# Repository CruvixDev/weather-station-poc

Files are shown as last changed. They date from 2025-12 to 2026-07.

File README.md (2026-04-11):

# Weather station POC (Proof Of Concept)




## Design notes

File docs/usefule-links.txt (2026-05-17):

https://developer.arm.com/documentation/dui0499/e/arm-dstream-target-interface-connections/swd-connections
https://www.emisoftware.com/calculator/microstrip-capacitance/
https://resources.altium.com/fr/p/pcb-design-and-review-checklist

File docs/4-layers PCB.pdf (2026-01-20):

Thickness: 1.6MM | Finished Outer Copper: 1OZ | Inner Copper: 1OZ | Inner layer Residual copper ratio: 30%
Layer | Material | Thickness
| | | (mm) Thickness after lamination(mm)
| | L1-CU | Outer Base Copper
0.5OZ | 0.0175 | 0.0175
| | | (Plating to 1OZ)
| | PP | 7628 RC46%
DK:4.74 | 0.1960 | 0.1715
L2-CU | Inner Copper 1OZ | 0.0350
| | | 1.1
(Core with Cu) CORE | Core
DK:4.6 | 1.0300
L3-CU | Inner Copper 1OZ | 0.0350
PP | 7628 RC46%
DK:4.74 | 0.1960 | 0.1715
L4-CU | Outer Base Copper
0.5OZ | 0.0175 | 0.0175
(Plating to 1OZ)

L2-CU

L1-CU

PP

## CORE

L3-CU

PP

L4-CU

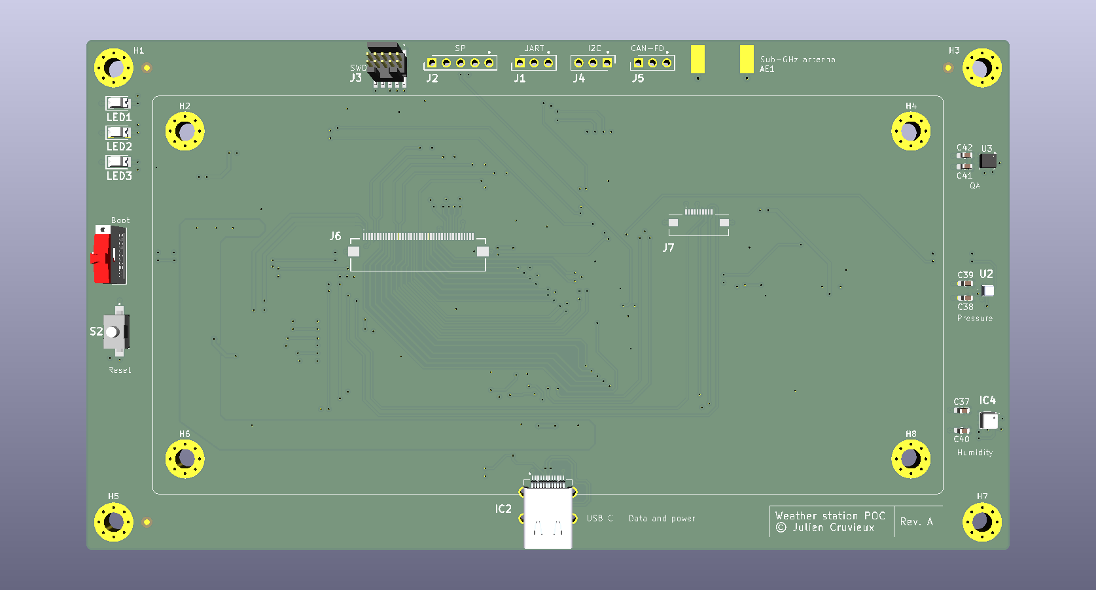
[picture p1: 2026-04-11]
docs/weather-station-poc-top.png

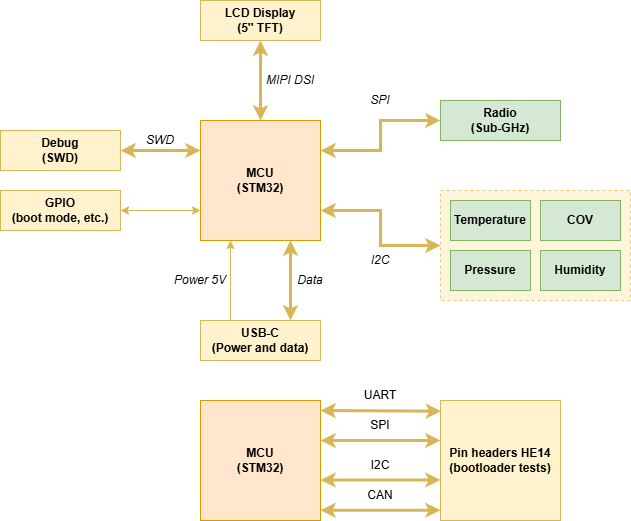
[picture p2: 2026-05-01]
docs/WeatherStationPOC.png

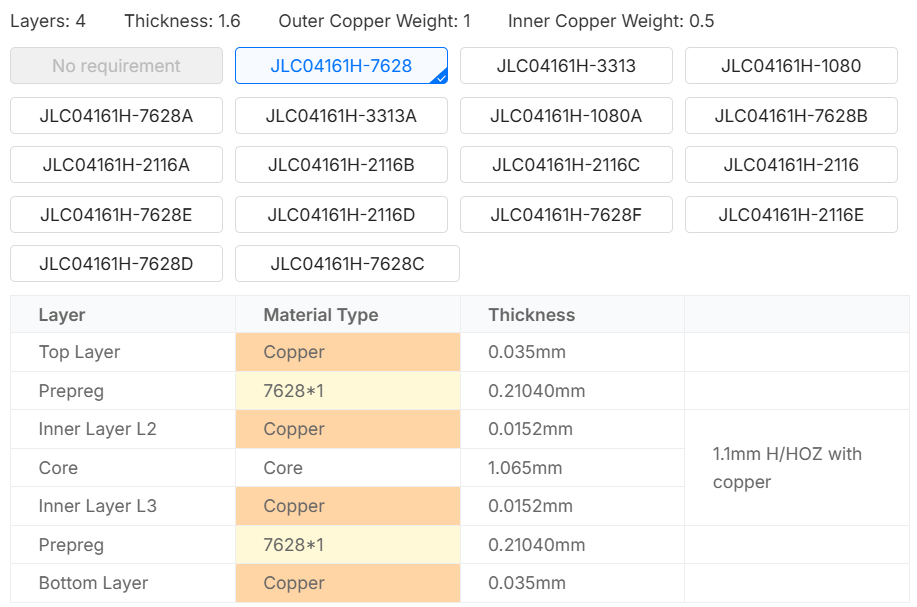
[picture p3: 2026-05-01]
docs/stackup-jlcpcb.png

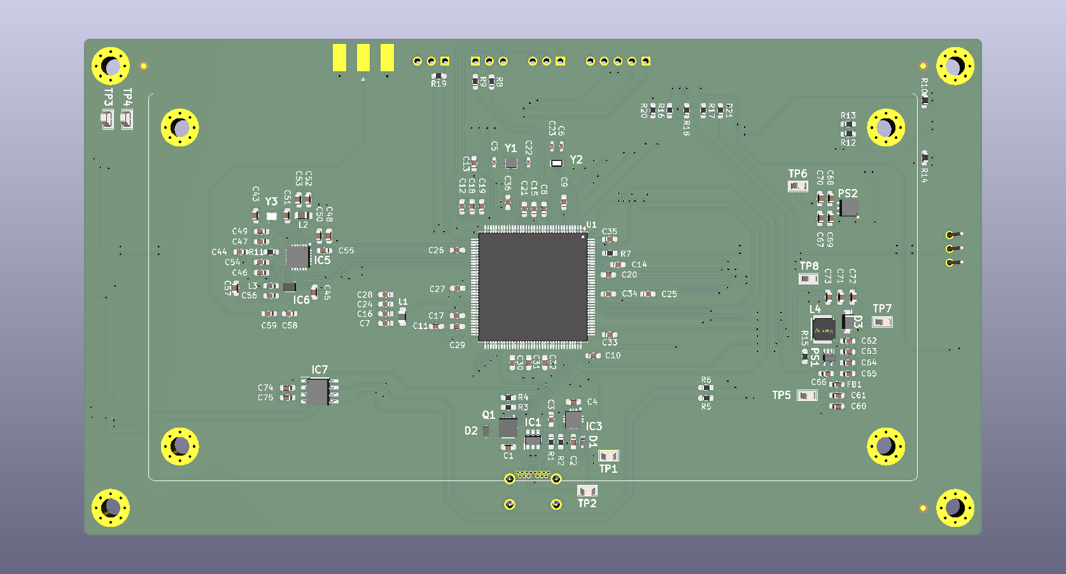
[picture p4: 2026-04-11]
docs/weather-station-poc-bottom.png

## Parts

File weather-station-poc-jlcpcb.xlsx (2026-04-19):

Comment | Designator | Footprint
Antenna | AE1 | Connector_Coaxial:SMA_Molex_73251-1153_EdgeMount_Horizontal
100p | C1,C45,C46,C49,C58 | Capacitor_SMD:C_0603_1608Metric_Pad1.08x0.95mm_HandSolder
100n | C2,C4,C7,C8,C9,C10,C16,C17,C18,C19,C20,C21,C25,C26,C27,C29,C30,C31,C32,C33,C34,C35,C36,C37,C38,C39,C41,C42,C60,C62,C66,C69,C70,C71,C73,C75 | Capacitor_SMD:C_0603_1608Metric_Pad1.08x0.95mm_HandSolder
470p | C3,C54 | Capacitor_SMD:C_0603_1608Metric_Pad1.08x0.95mm_HandSolder
8p | C5,C22 | Capacitor_SMD:C_0402_1005Metric_Pad0.74x0.62mm_HandSolder
3p | C6,C23 | Capacitor_SMD:C_0402_1005Metric_Pad0.74x0.62mm_HandSolder
10u | C11,C15,C61,C63,C64,C65,C74 | Capacitor_SMD:C_0603_1608Metric_Pad1.08x0.95mm_HandSolder
1u | C12,C13,C53,C67,C68 | Capacitor_SMD:C_0603_1608Metric_Pad1.08x0.95mm_HandSolder
4u7 | C14,C48,C72 | Capacitor_SMD:C_0603_1608Metric_Pad1.08x0.95mm_HandSolder
2u2 | C24,C28 | Capacitor_SMD:C_0603_1608Metric_Pad1.08x0.95mm_HandSolder
220n | C40 | Capacitor_SMD:C_0603_1608Metric_Pad1.08x0.95mm_HandSolder
10p | C43 | Capacitor_SMD:C_0603_1608Metric_Pad1.08x0.95mm_HandSolder
150n | C44,C47,C50,C52,C55,C56,C57 | Capacitor_SMD:C_0603_1608Metric_Pad1.08x0.95mm_HandSolder
12p | C51 | Capacitor_SMD:C_0603_1608Metric_Pad1.08x0.95mm_HandSolder
2p7 | C59 | Capacitor_SMD:C_0603_1608Metric_Pad1.08x0.95mm_HandSolder
BAT54KFILM | D1 | weather-station-poc-fp:SODFL1608X70N
ESDA25P35-1U1M | D2 | weather-station-poc-fp:ESDA25P351U1M
SS26FL | D3 | weather-station-poc-fp:SODFL3617X108N
70 | FB1 | Inductor_SMD:L_0603_1608Metric_Pad1.05x0.95mm_HandSolder
USBLC6-2SC6 | IC1 | weather-station-poc-fp:SOT95P280X145-6N
6,32723E+11 | IC2 | weather-station-poc-fp:632723100011
TCPP01-M12 | IC3 | weather-station-poc-fp:QFN50P300X300X100-13N-D
BME690 | IC4 | weather-station-poc-fp:BME690
S2-LPQTR | IC5 | weather-station-poc-fp:QFN50P400X400X100-25N-D
BALF-SPI2-01D3 | IC6 | weather-station-poc-fp:BALFSPI201D3
STSAFA110S8OCD03 | IC7 | weather-station-poc-fp:SOIC127P600X175-8N
61300311121 | J1,J4,J5 | weather-station-poc-fp:HDRV3W64P0X254_1X3_762X254X869P
61300511121 | J2 | weather-station-poc-fp:HDRV5W64P0X254_1X5_1270X254X854P
Conn_ARM_JTAG_SWD_10 | J3 | weather-station-poc-fp:FTSH10501LDVK
6,8714E+11 | J6 | weather-station-poc-fp:687140149022
6,8711E+11 | J7 | weather-station-poc-fp:687110183622
2u2 | L1 | Inductor_SMD:L_0805_2012Metric_Pad1.05x1.20mm_HandSolder
10u | L2 | Inductor_SMD:L_0805_2012Metric_Pad1.05x1.20mm_HandSolder
12n | L3 | Inductor_SMD:L_0603_1608Metric_Pad1.05x0.95mm_HandSolder
10u | L4 | weather-station-poc-fp:INDPM4040X180N
HSMG-C150 | LED1,LED2,LED3 | weather-station-poc-fp:LEDC3216X120N
TPS61169DCKR | PS1 | weather-station-poc-fp:SOT65P210X110-5N
LD39050PU33R | PS2 | weather-station-poc-fp:SON95P300X300X100-7N-D
STL11N3LLH6 | Q1 | weather-station-poc-fp:STL20N6F7
10k | R1,R7,R10,R18,R20,R21 | Resistor_SMD:R_0603_1608Metric_Pad0.98x0.95mm_HandSolder
2k4 | R2 | Resistor_SMD:R_0603_1608Metric_Pad0.98x0.95mm_HandSolder
110k | R3 | Resistor_SMD:R_0603_1608Metric_Pad0.98x0.95mm_HandSolder
200k | R4 | Resistor_SMD:R_0603_1608Metric_Pad0.98x0.95mm_HandSolder
4.7k | R5,R6,R8,R9 | Resistor_SMD:R_0603_1608Metric_Pad0.98x0.95mm_HandSolder
10 | R11 | Resistor_SMD:R_0603_1608Metric_Pad0.98x0.95mm_HandSolder
1k | R12,R14 | Resistor_SMD:R_0603_1608Metric_Pad0.98x0.95mm_HandSolder
2k | R13 | Resistor_SMD:R_0603_1608Metric_Pad0.98x0.95mm_HandSolder
1R5 | R15 | Resistor_SMD:R_0603_1608Metric_Pad0.98x0.95mm_HandSolder
22 | R16,R17 | Resistor_SMD:R_0603_1608Metric_Pad0.98x0.95mm_HandSolder
120 | R19 | Resistor_SMD:R_0603_1608Metric_Pad0.98x0.95mm_HandSolder
4,50301E+11 | S1 | weather-station-poc-fp:450301014042
4,34121E+11 | S2 | weather-station-poc-fp:434121050816
TestPoint | TP1,TP2,TP3,TP4,TP5,TP6,TP7,TP8 | weather-station-poc-fp:5015
STM32U5G9ZJTxQ | U1 | Package_QFP:LQFP-144_20x20mm_P0.5mm
BMP581 | U2 | weather-station-poc-fp:BMP581
BME280 | U3 | Package_LGA:Bosch_LGA-8_2.5x2.5mm_P0.65mm_ClockwisePinNumbering
NX2016SA-16MHZ-EXS00A-CS07826 | Y1 | weather-station-poc-fp:NX2016SA16MHZEXS00ACS07826
NX2012SA-32.768K-STD-MUB-1 | Y2 | weather-station-poc-fp:NX2012SA32768KSTDMUB1
NX1612SA-50M-EXS00A-CS08403 | Y3 | weather-station-poc-fp:NX1612SA50MEXS00ACS08403

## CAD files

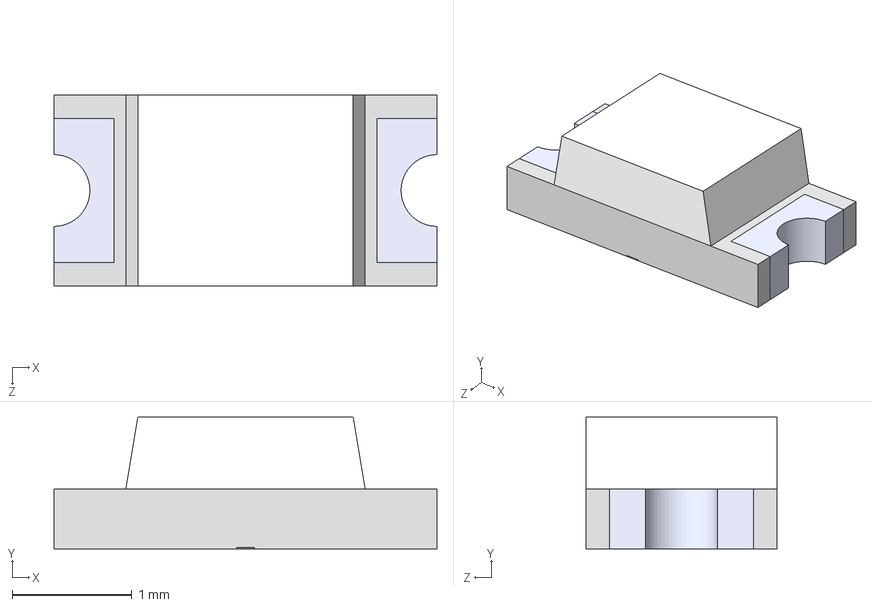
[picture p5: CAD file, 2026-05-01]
3d_models/HSMG-C150.stp
3.20 x 1.10 x 1.60 mm

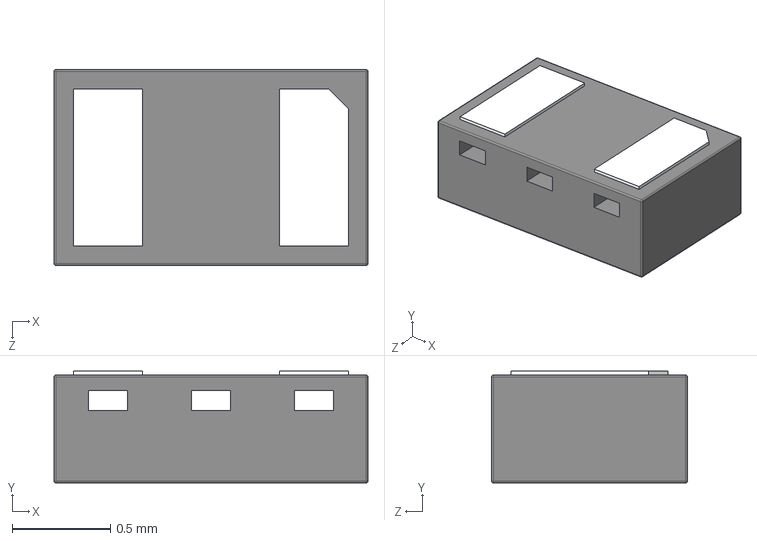
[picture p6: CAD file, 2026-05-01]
3d_models/ESDA25P35-1U1M.stp
1.60 x 0.57 x 1.00 mm

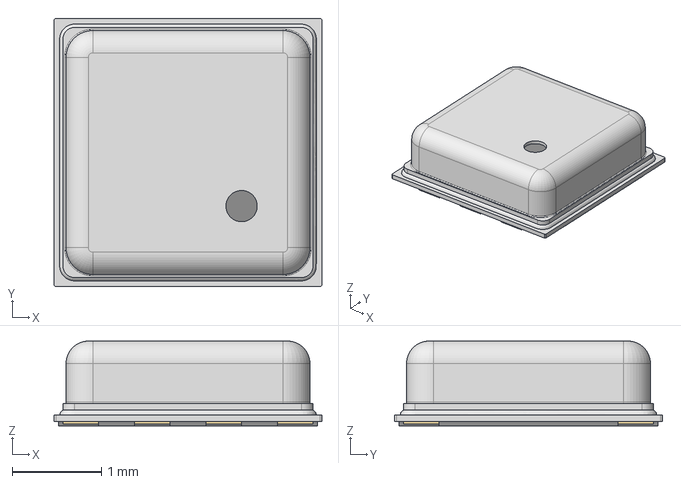
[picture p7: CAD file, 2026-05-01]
3d_models/BME690.stp
3.00 x 3.00 x 0.95 mm

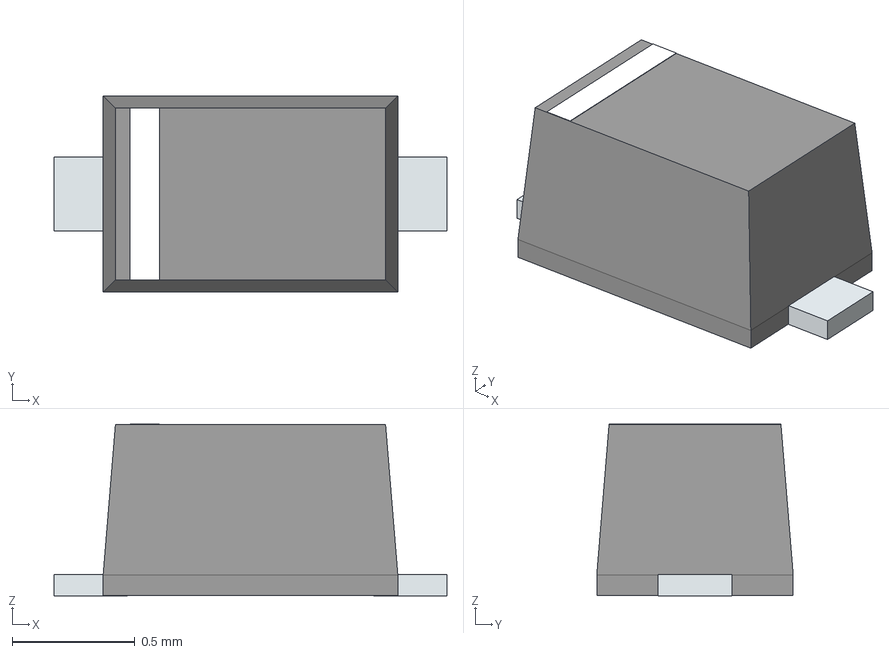
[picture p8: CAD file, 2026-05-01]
3d_models/BAT54KFILM.stp
1.60 x 0.8 x 0.7 mm
PinKIdent
PinK
PinA

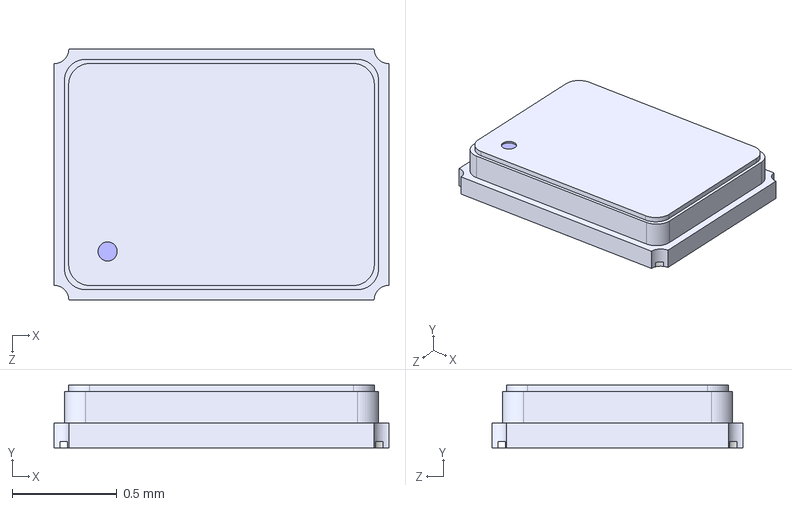
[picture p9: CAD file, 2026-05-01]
3d_models/NX1612SA-50M-EXS00A-CS08403.stp
1.60 x 0.3 x 1.20 mm

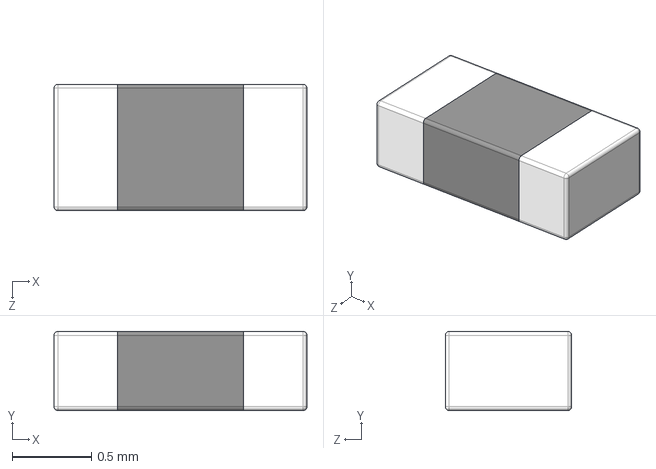
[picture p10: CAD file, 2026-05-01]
3d_models/BLM18SG700TN1D.stp
1.60 x 0.5 x 0.8 mm

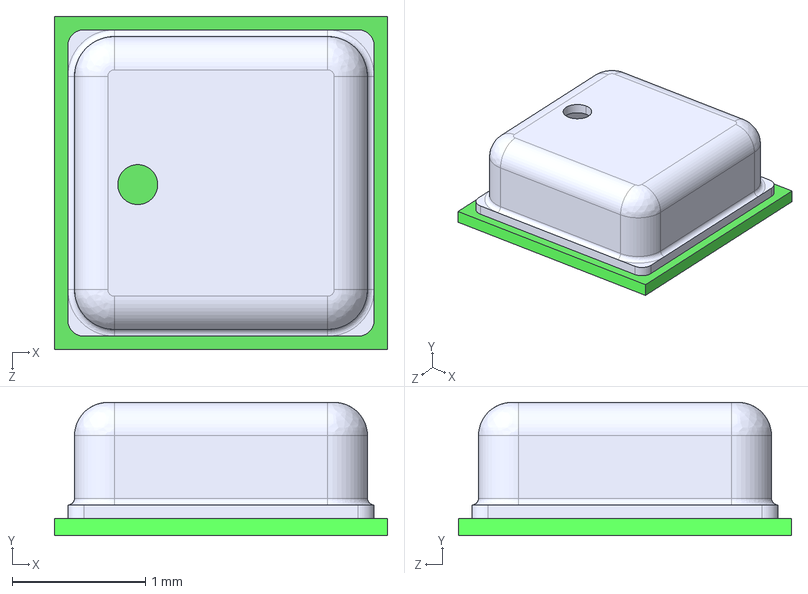
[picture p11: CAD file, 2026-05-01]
3d_models/BME280.stp
2.50 x 1.00 x 2.50 mm

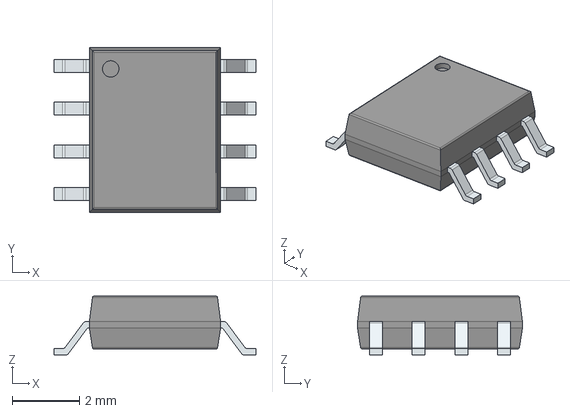
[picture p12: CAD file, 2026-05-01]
3d_models/STSAFA110S8OCD03.stp
6.00 x 4.90 x 1.75 mm
PinsArrayLR

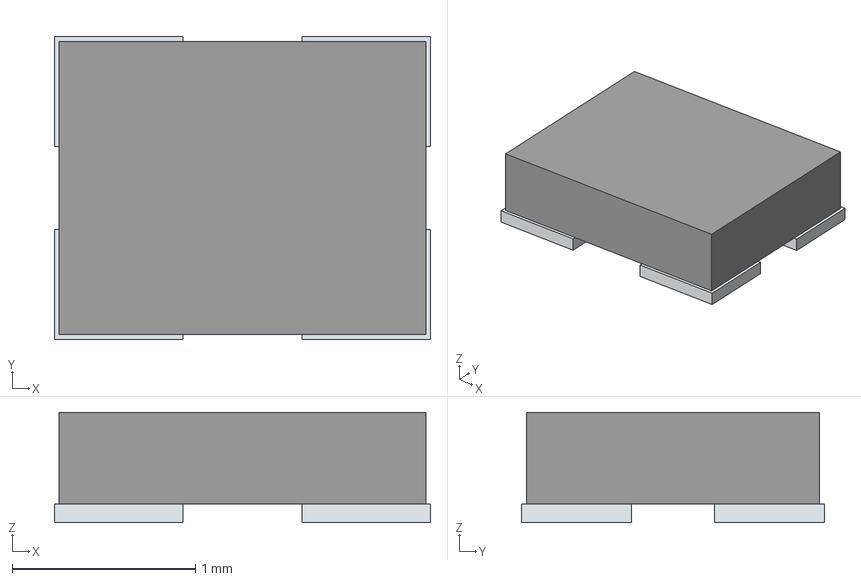
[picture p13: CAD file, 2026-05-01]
3d_models/NX2016SA-16MHZ-EXS00A-CS07826.stp
2.05 x 1.65 x 0.6 mm
Pins

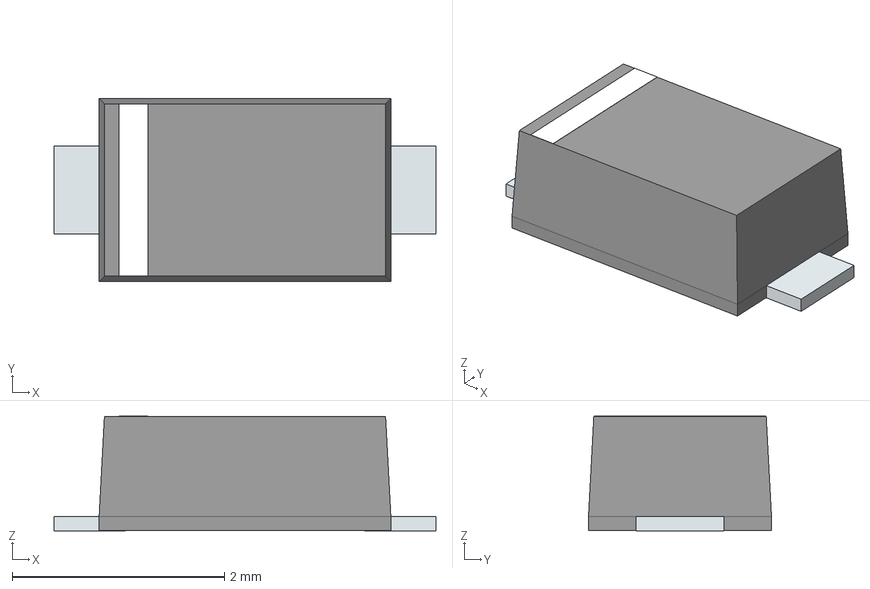
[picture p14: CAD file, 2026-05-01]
3d_models/SS26FL.stp
3.60 x 1.73 x 1.08 mm
PinKIdent
PinK
PinA

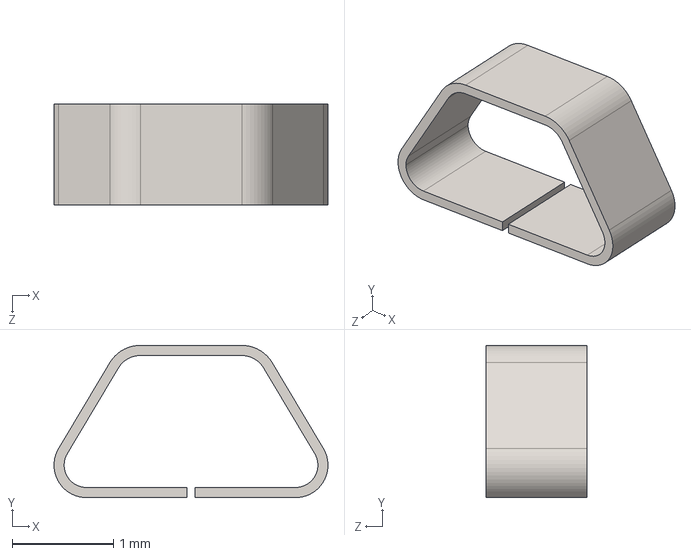
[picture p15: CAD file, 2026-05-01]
3d_models/5015.stp
2.70 x 1.50 x 1.00 mm

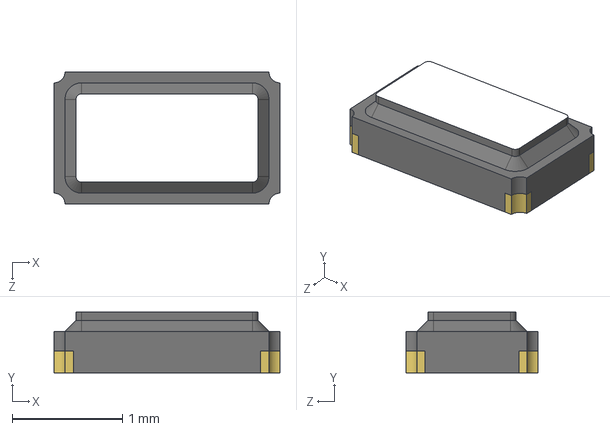
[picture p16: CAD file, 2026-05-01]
3d_models/NX2012SA-32.768K-STD-MUB-1.stp
2.05 x 0.55 x 1.20 mm

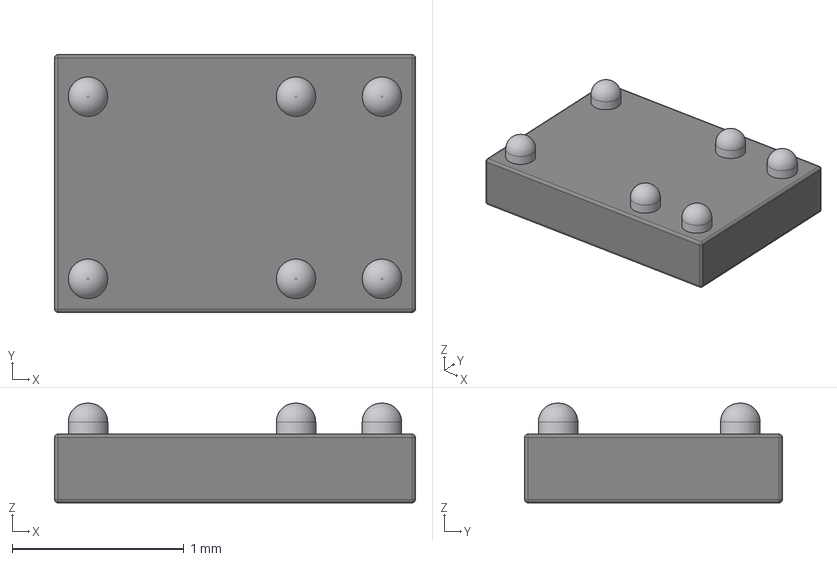
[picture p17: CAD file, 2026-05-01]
3d_models/BALF-SPI2-01D3.stp
2.10 x 1.50 x 0.58 mm

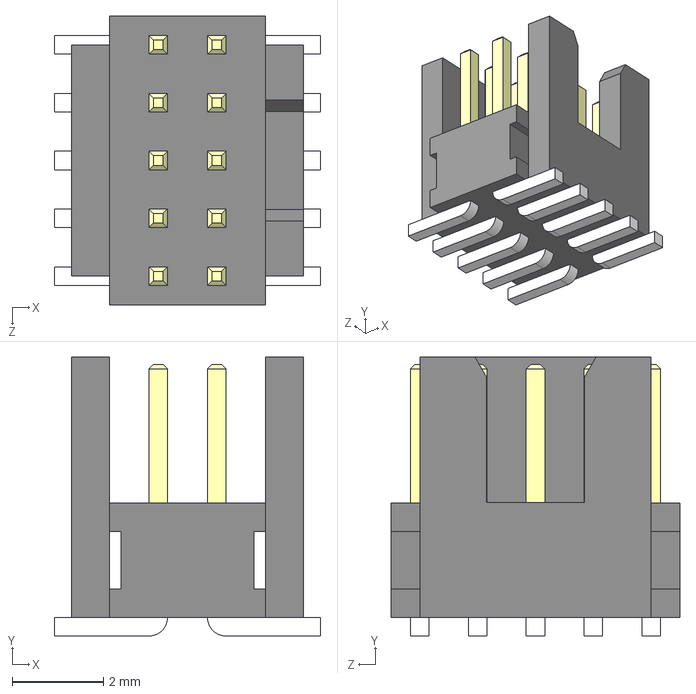
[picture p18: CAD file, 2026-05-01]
3d_models/FTSH-105-01-L-DV-K.stp
5.85 x 6.13 x 6.35 mm

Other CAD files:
3d_models/S2-LPQTR.stp
3d_models/STL11N3LLH6.stp
3d_models/USBLC6-2SC6.stp
3d_models/TCPP01-M12.stp
3d_models/434121025816.stp
3d_models/450301014042.stp
3d_models/632723100011.stp
3d_models/687110149022.stp
3d_models/74404042100.stp
3d_models/7499210001A.stp
3d_models/BMP581.stp
3d_models/LD39050PU33R.stp
3d_models/TPS61169DCKR.stp

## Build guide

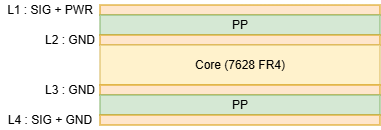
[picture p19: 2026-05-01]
docs/build-up.png

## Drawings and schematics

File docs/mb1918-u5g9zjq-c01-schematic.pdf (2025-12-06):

Title: Project_Overview

Size:

Reference:
A4 | Sheet: | of

Revision:

Project: STM32U5G9ZJT6Q Discovery

C 01 | MB1918
2023-07-05

U5G9ZJQ

Date:

Variant:

Table of contents | Legend

General comment such as function title, configuration, ...

Text to be added to silkscreen.

# STM32U5G9ZJT6Q Discovery

MB1918

Warning text.

# Open Platform License Agreement

The Open Platform License Agreement (“Agreement”) is a binding legal contract between you ("You")

and STMicroelectronics International N.V. (“ST”), a company incorporated under the laws of the

Netherlands acting for the purpose of this Agreement through its Swiss branch 39, Chemin du

Champ des Filles, 1228 Plan-les-Ouates, Geneva, Switzerland.

By using the enclosed reference designs, schematics, PC board layouts, and documentation, in hardcopy

or CAD tool file format (collectively, the “Reference Material”), You are agreeing to be bound by

the terms and conditions of this Agreement. Do not use the Reference Material until You have read

and agreed to this Agreement terms and conditions. The use of the Reference Material automatically

implies the acceptance of the Agreement terms and conditions.

The complete Open Platform License Agreement can be found on www.st.com/opla.

MB1918TOP

MB1918_TOP.SchDoc

Sheet 1: Project overview (this page)

Sheet 2: MB11918 TOP

Sheet 3: MCU System

Sheet 4: MCU Interfaces

Sheet 5: MCU Power

Sheet 6: Board Power

Sheet 7: Display

Sheet 8: USB Type C

Sheet 9: User Interface

Sheet 10: Octo SPI Flash Memory

Sheet 11: Arduino UNO Rev3Connectors

Sheet 12: STLINK V3EC

Sheet 13: External DebugConnectors

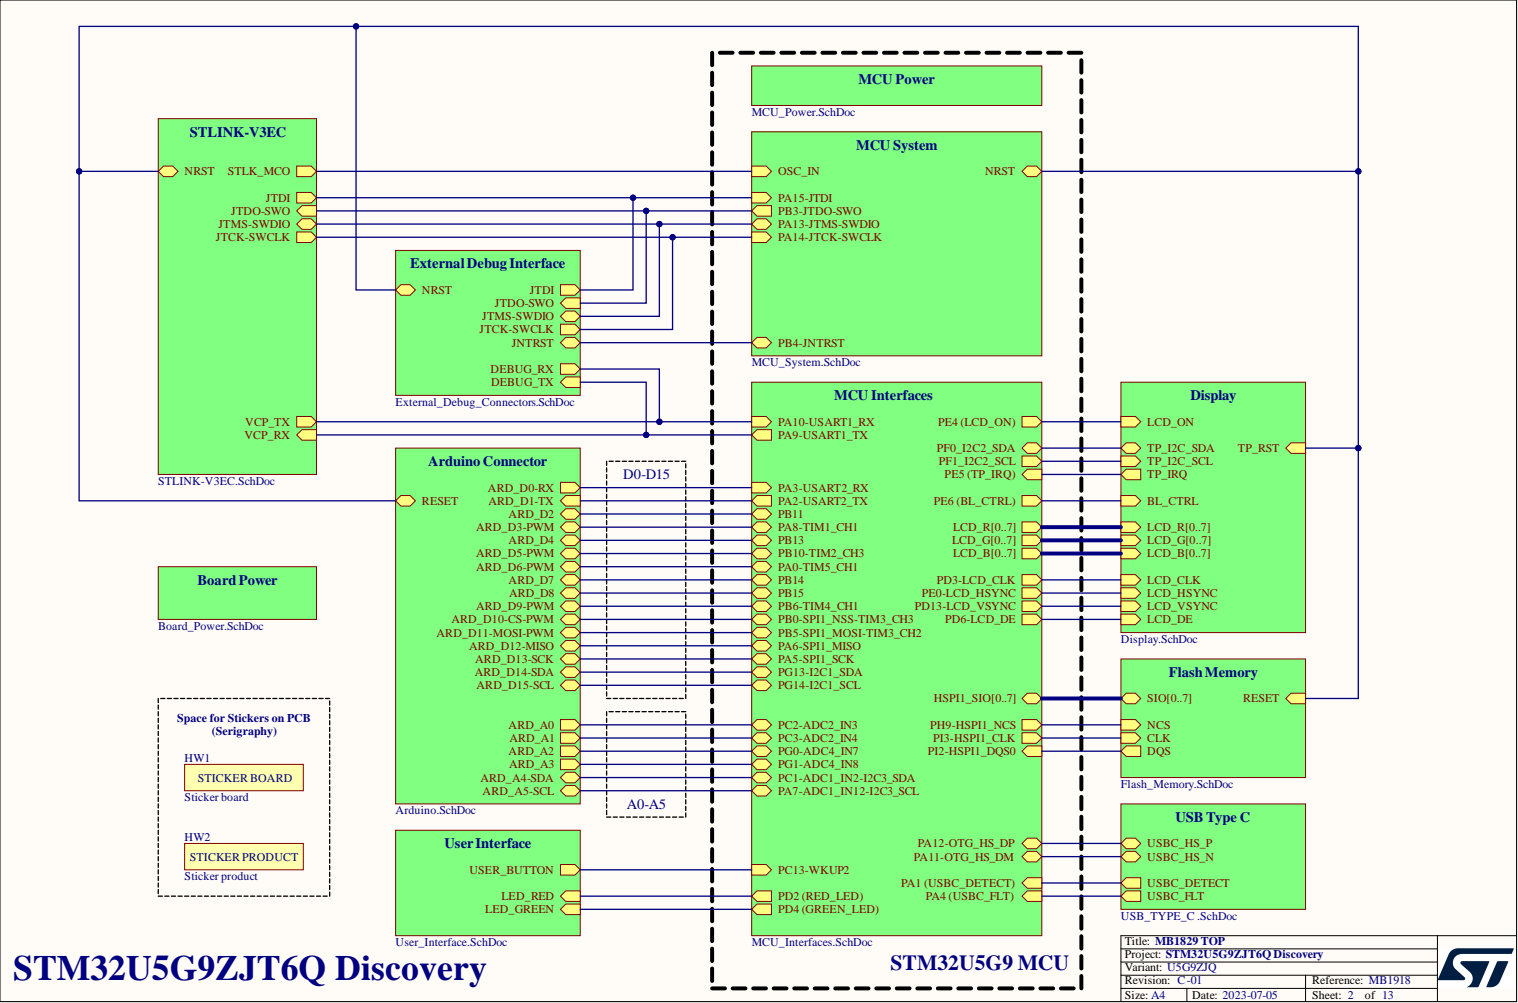
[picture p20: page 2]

Space for Stickers on PCB

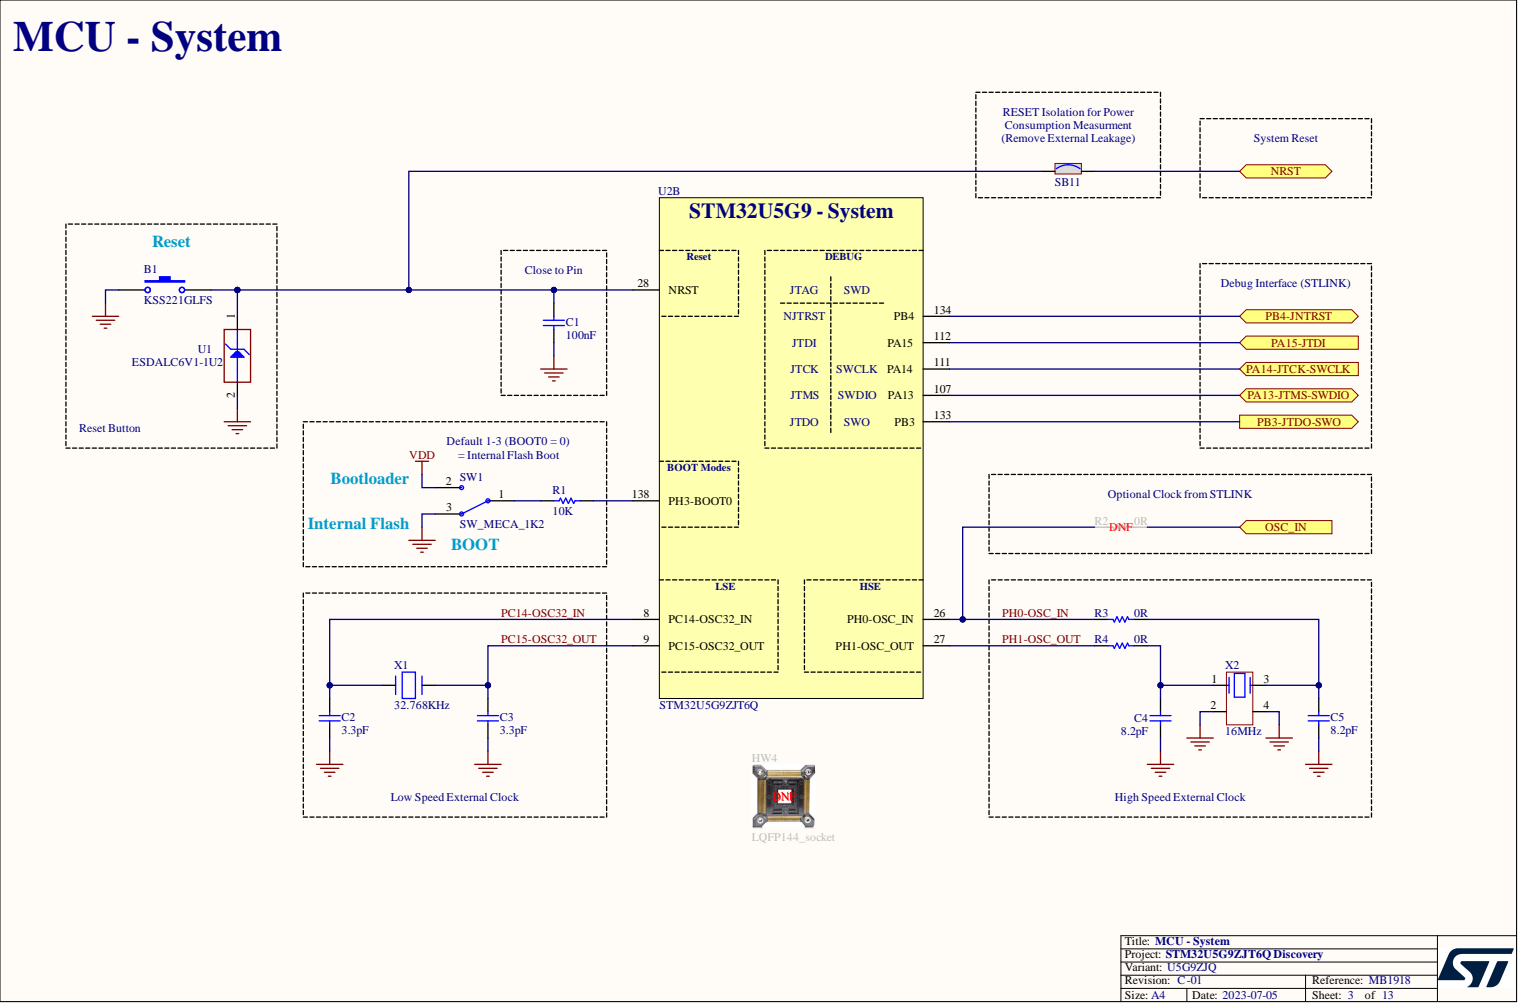
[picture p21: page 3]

RESET Isolation for Power
Consumption Measurment
(Remove External Leakage)

Optional Clock from STLINK

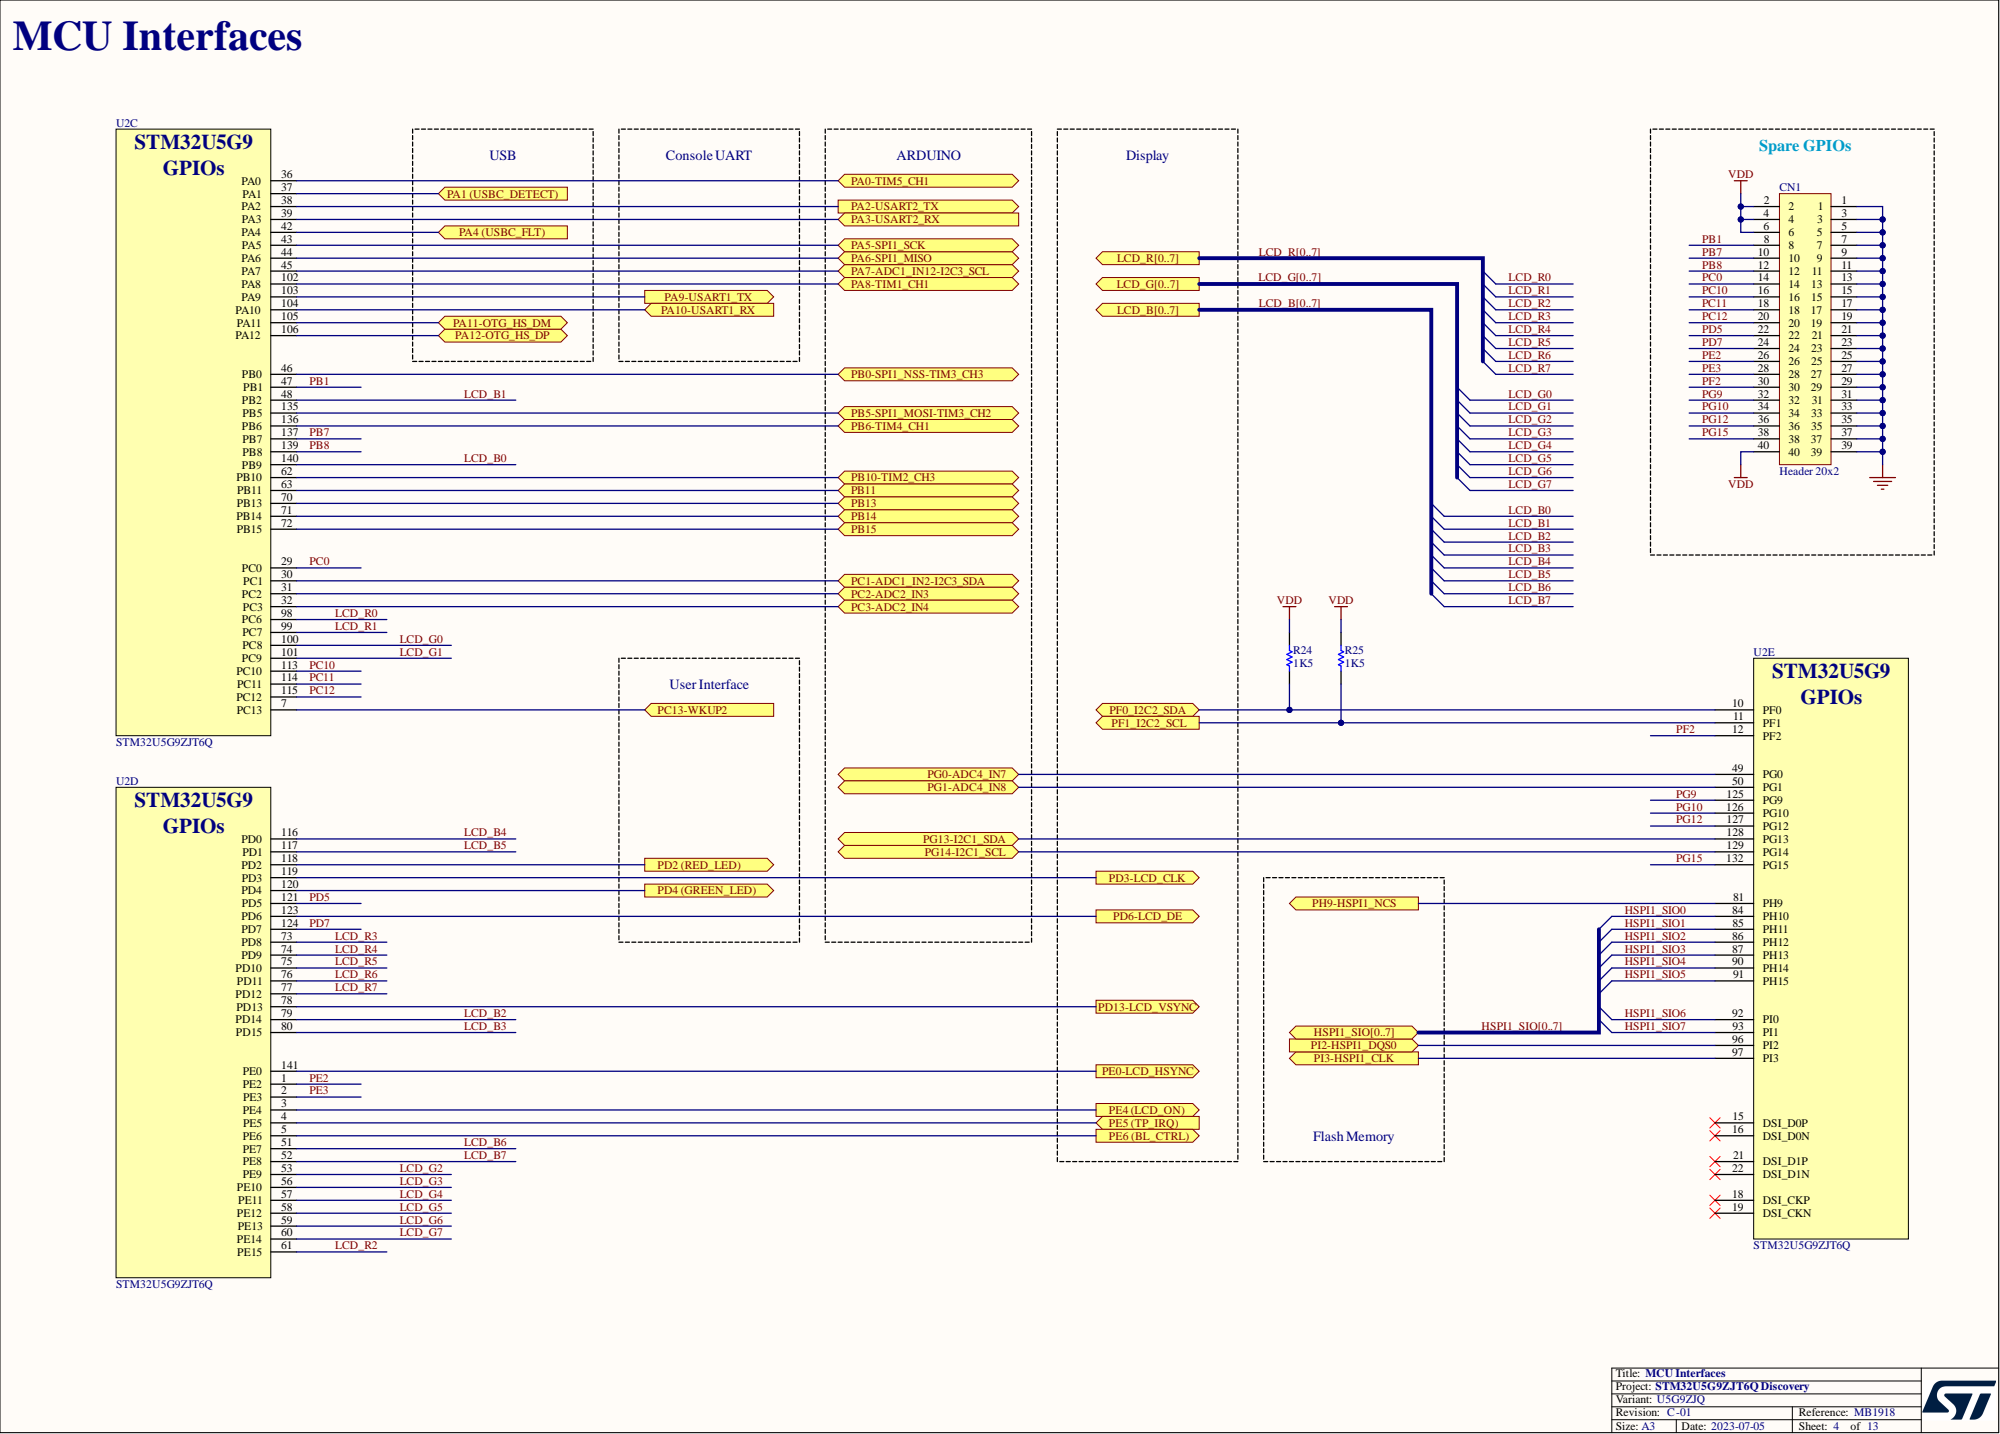
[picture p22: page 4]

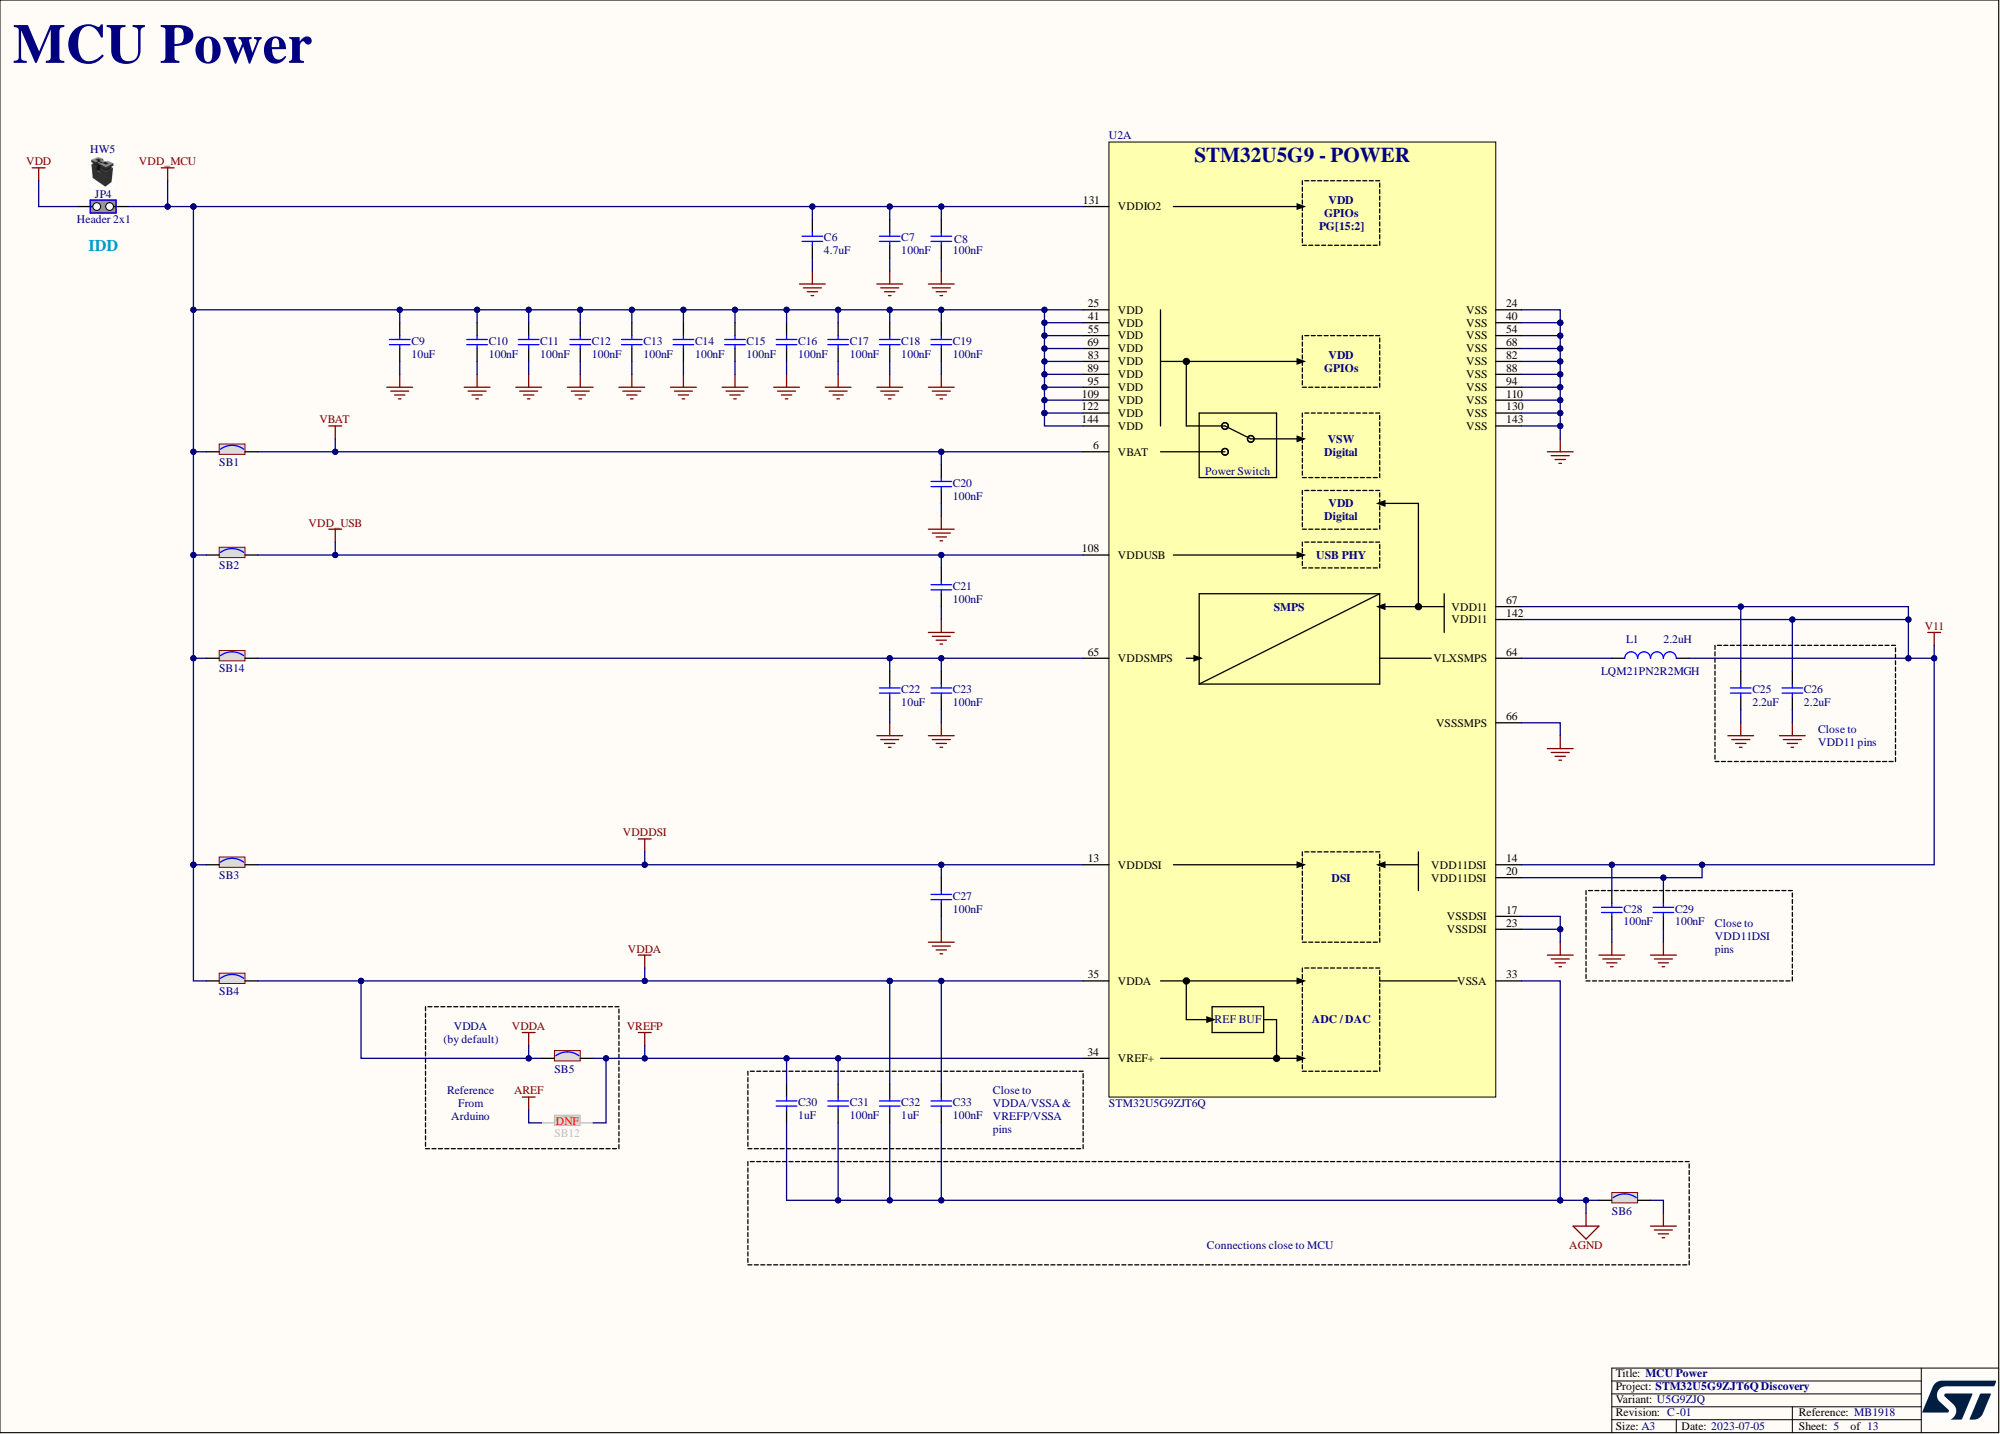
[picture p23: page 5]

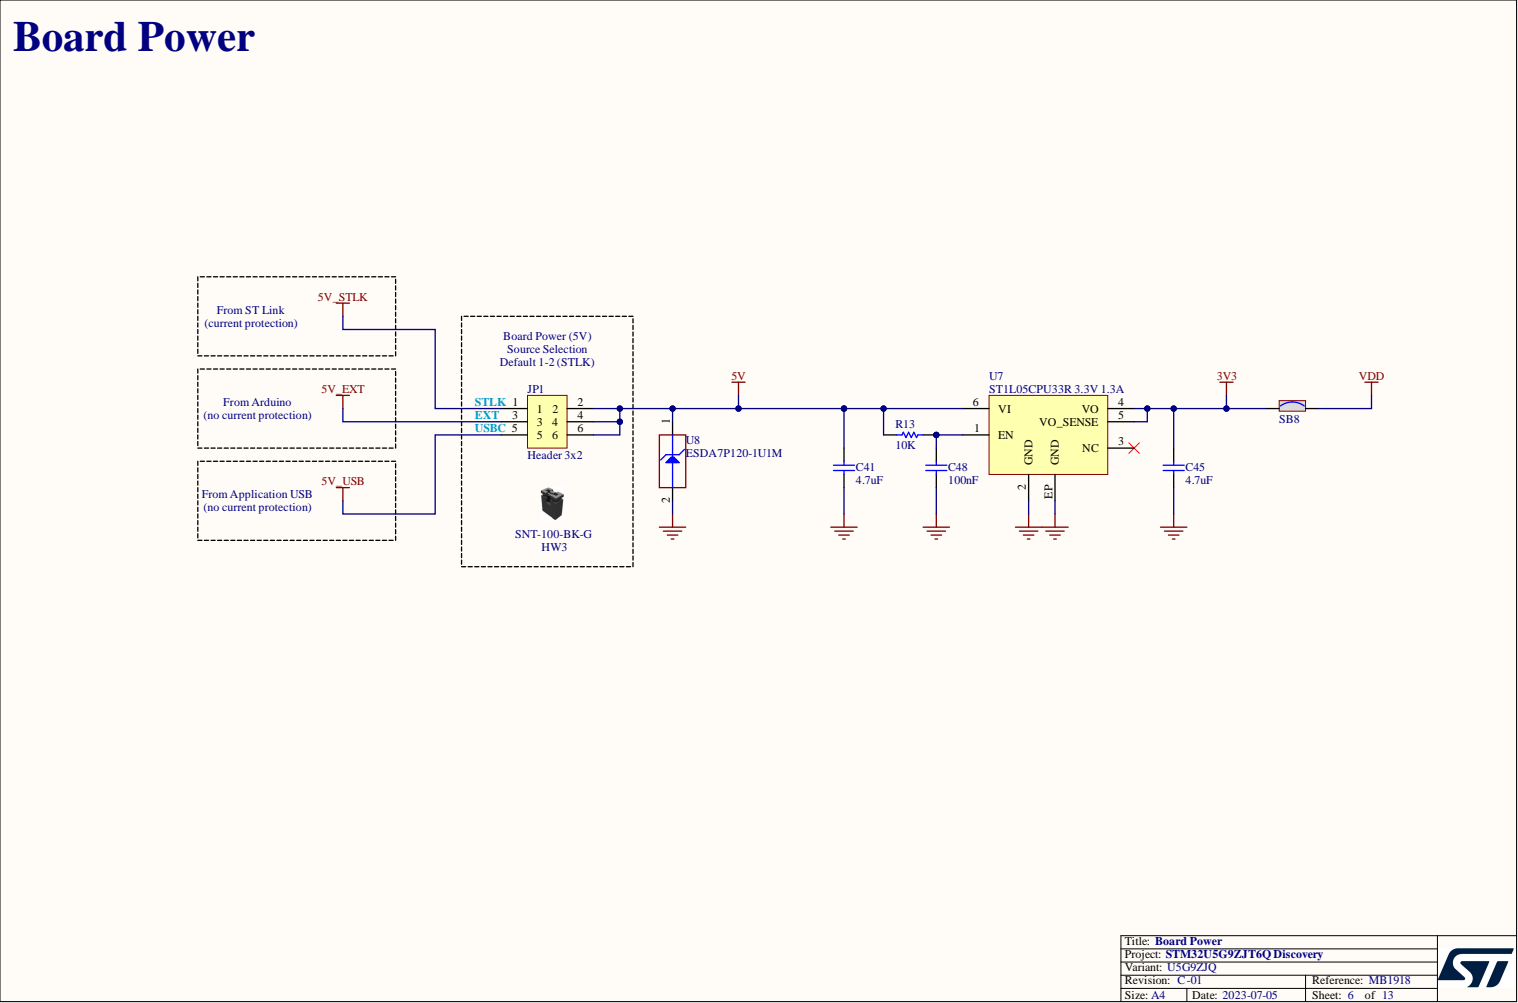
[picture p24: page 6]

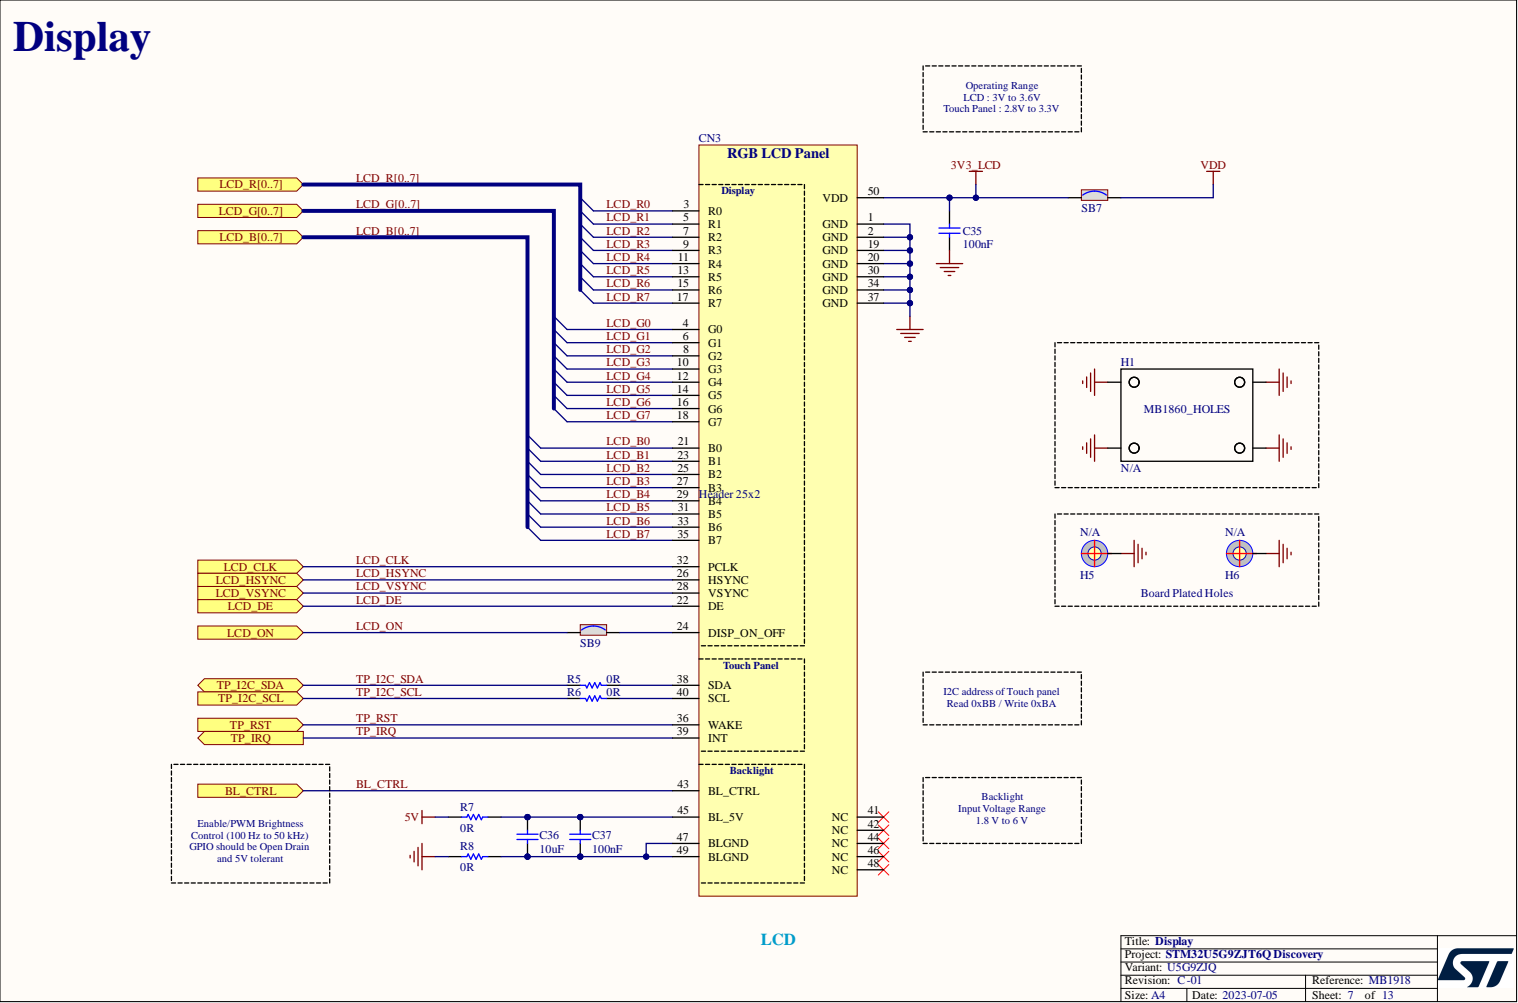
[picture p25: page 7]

PIO should be Open Dra
and 5V tol

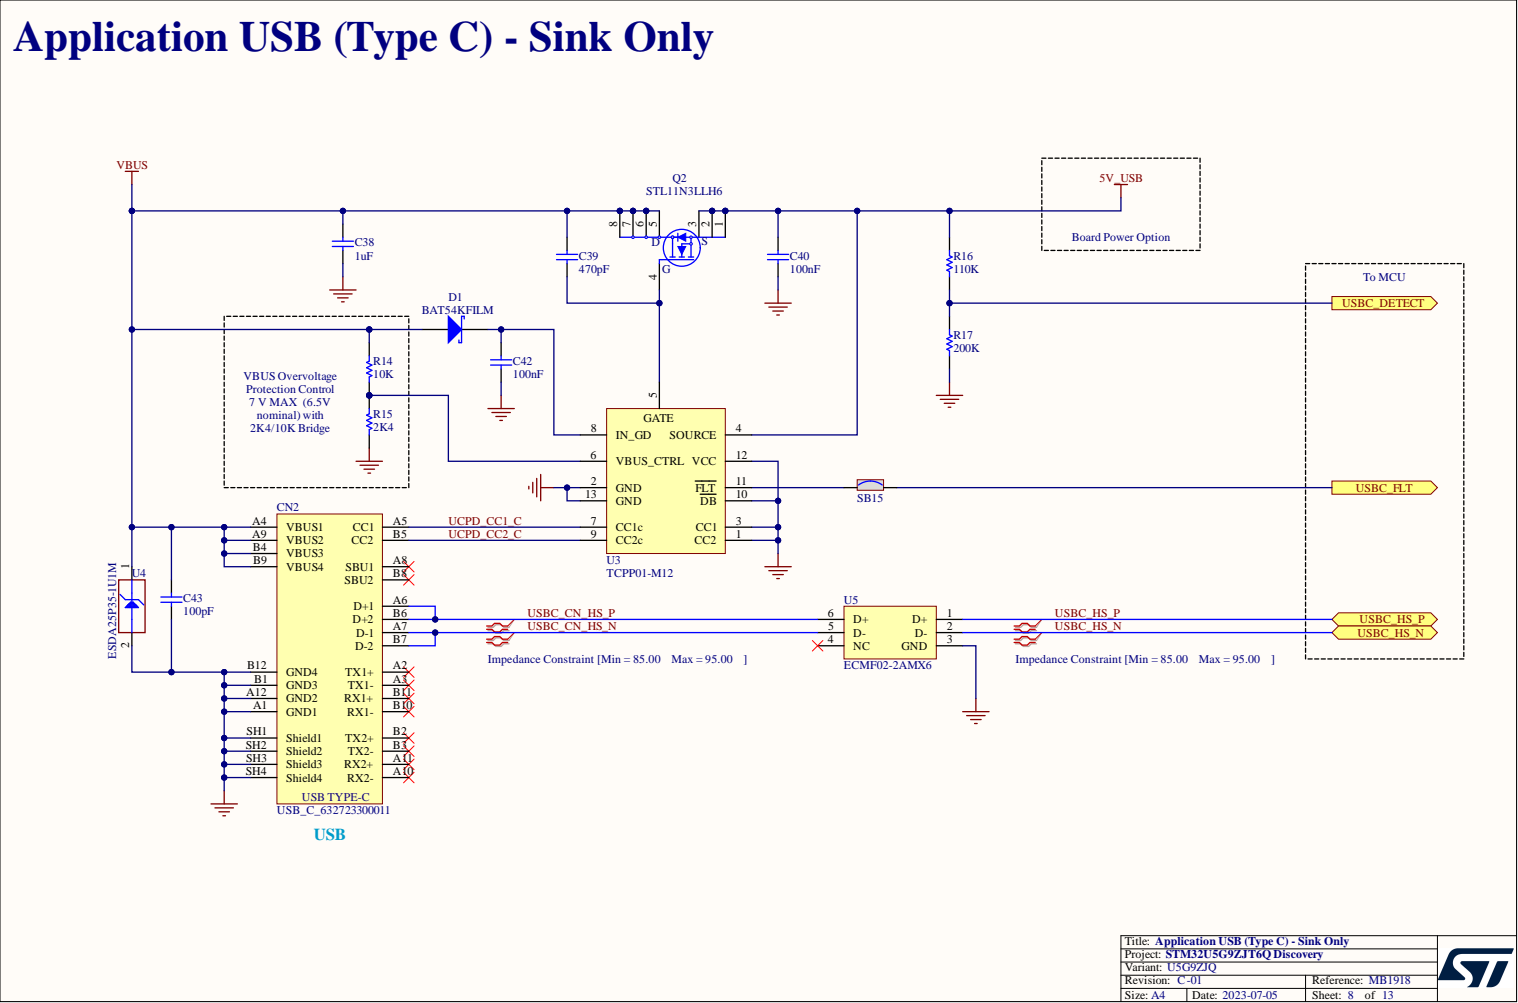
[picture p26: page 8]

Application USB (Type C) - Sink Only

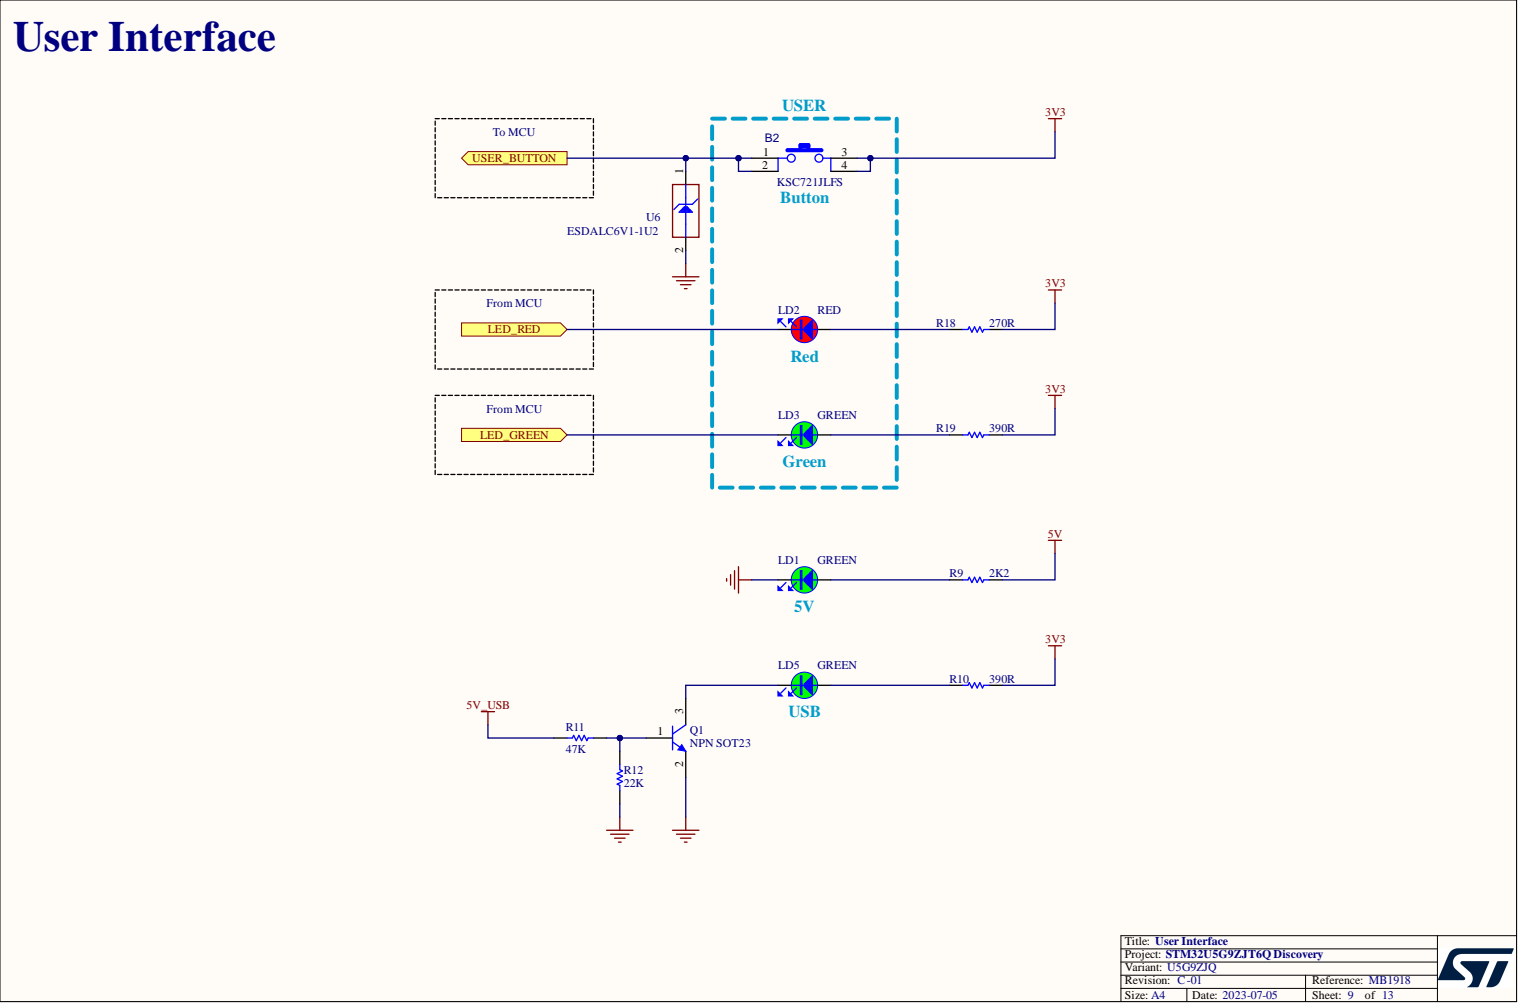
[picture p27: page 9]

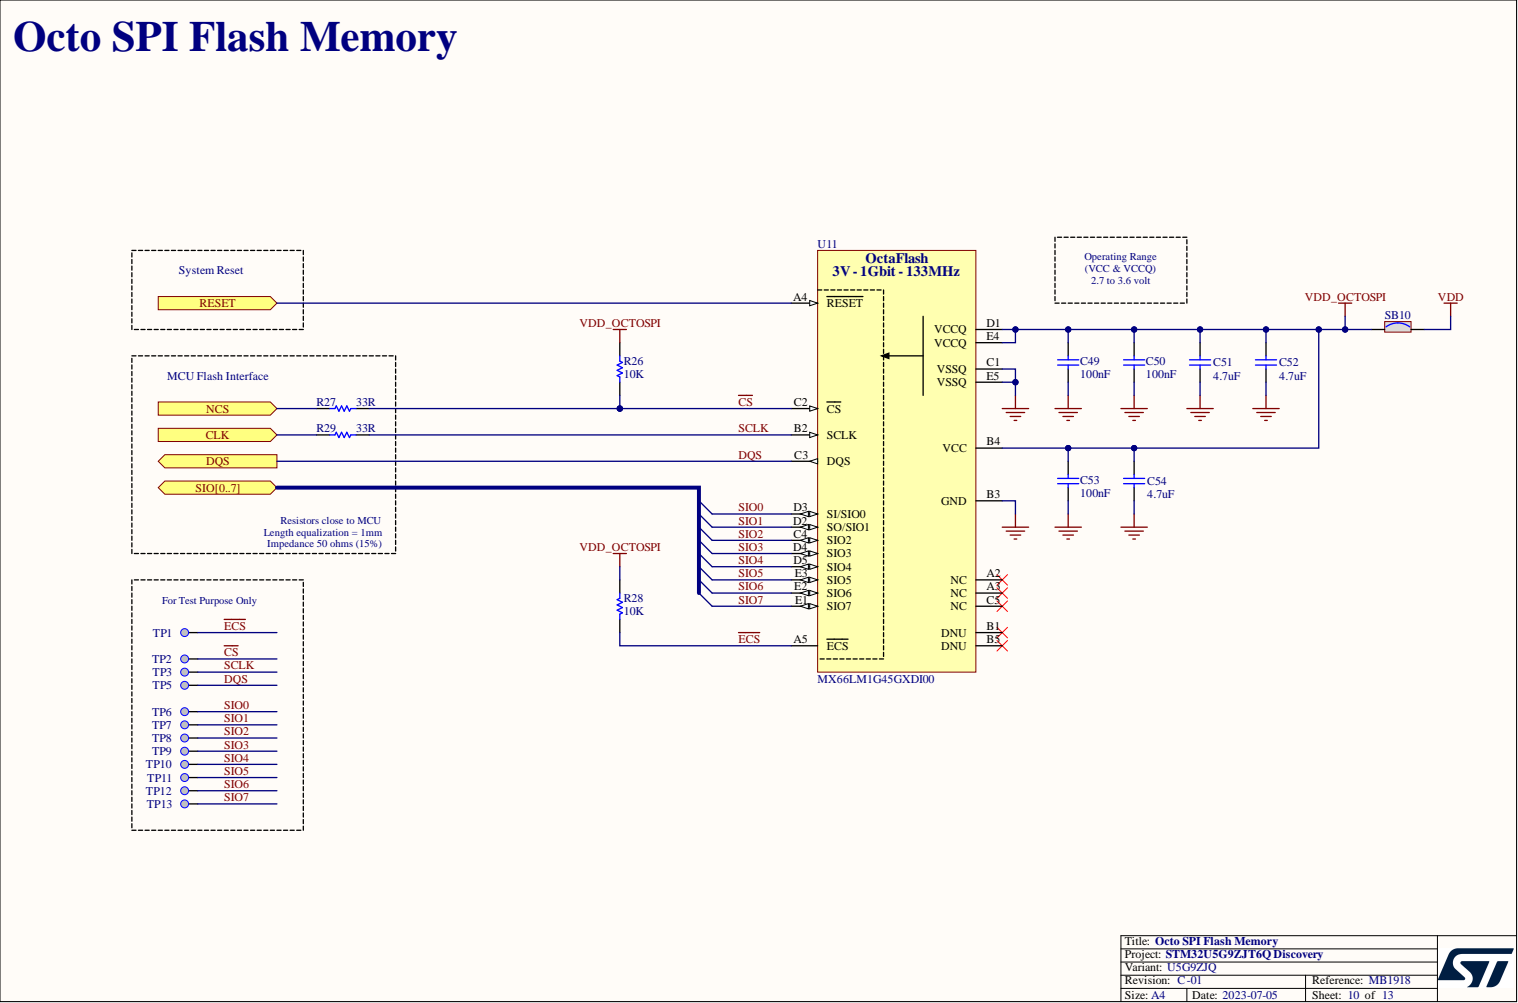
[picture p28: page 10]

Octo SPI Flash Memory

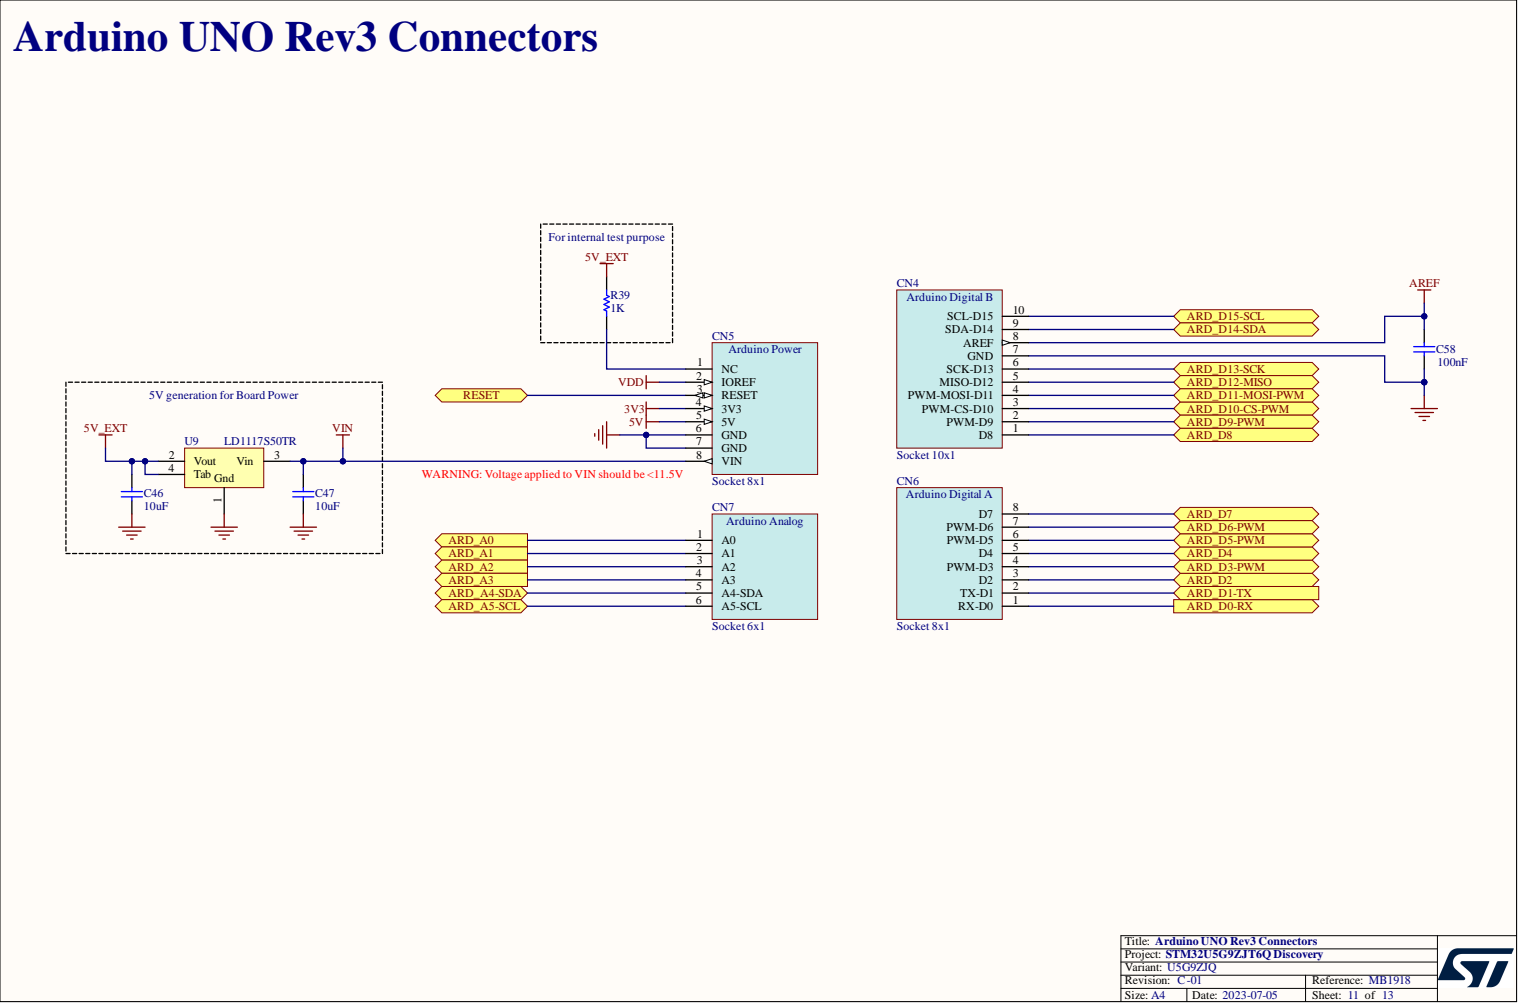
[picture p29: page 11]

Arduino UNO Rev3 Connectors ARD_A0 ARD_A4-SDA ARD_A5-SCL ARD_A1 ARD_A2 ARD_A3

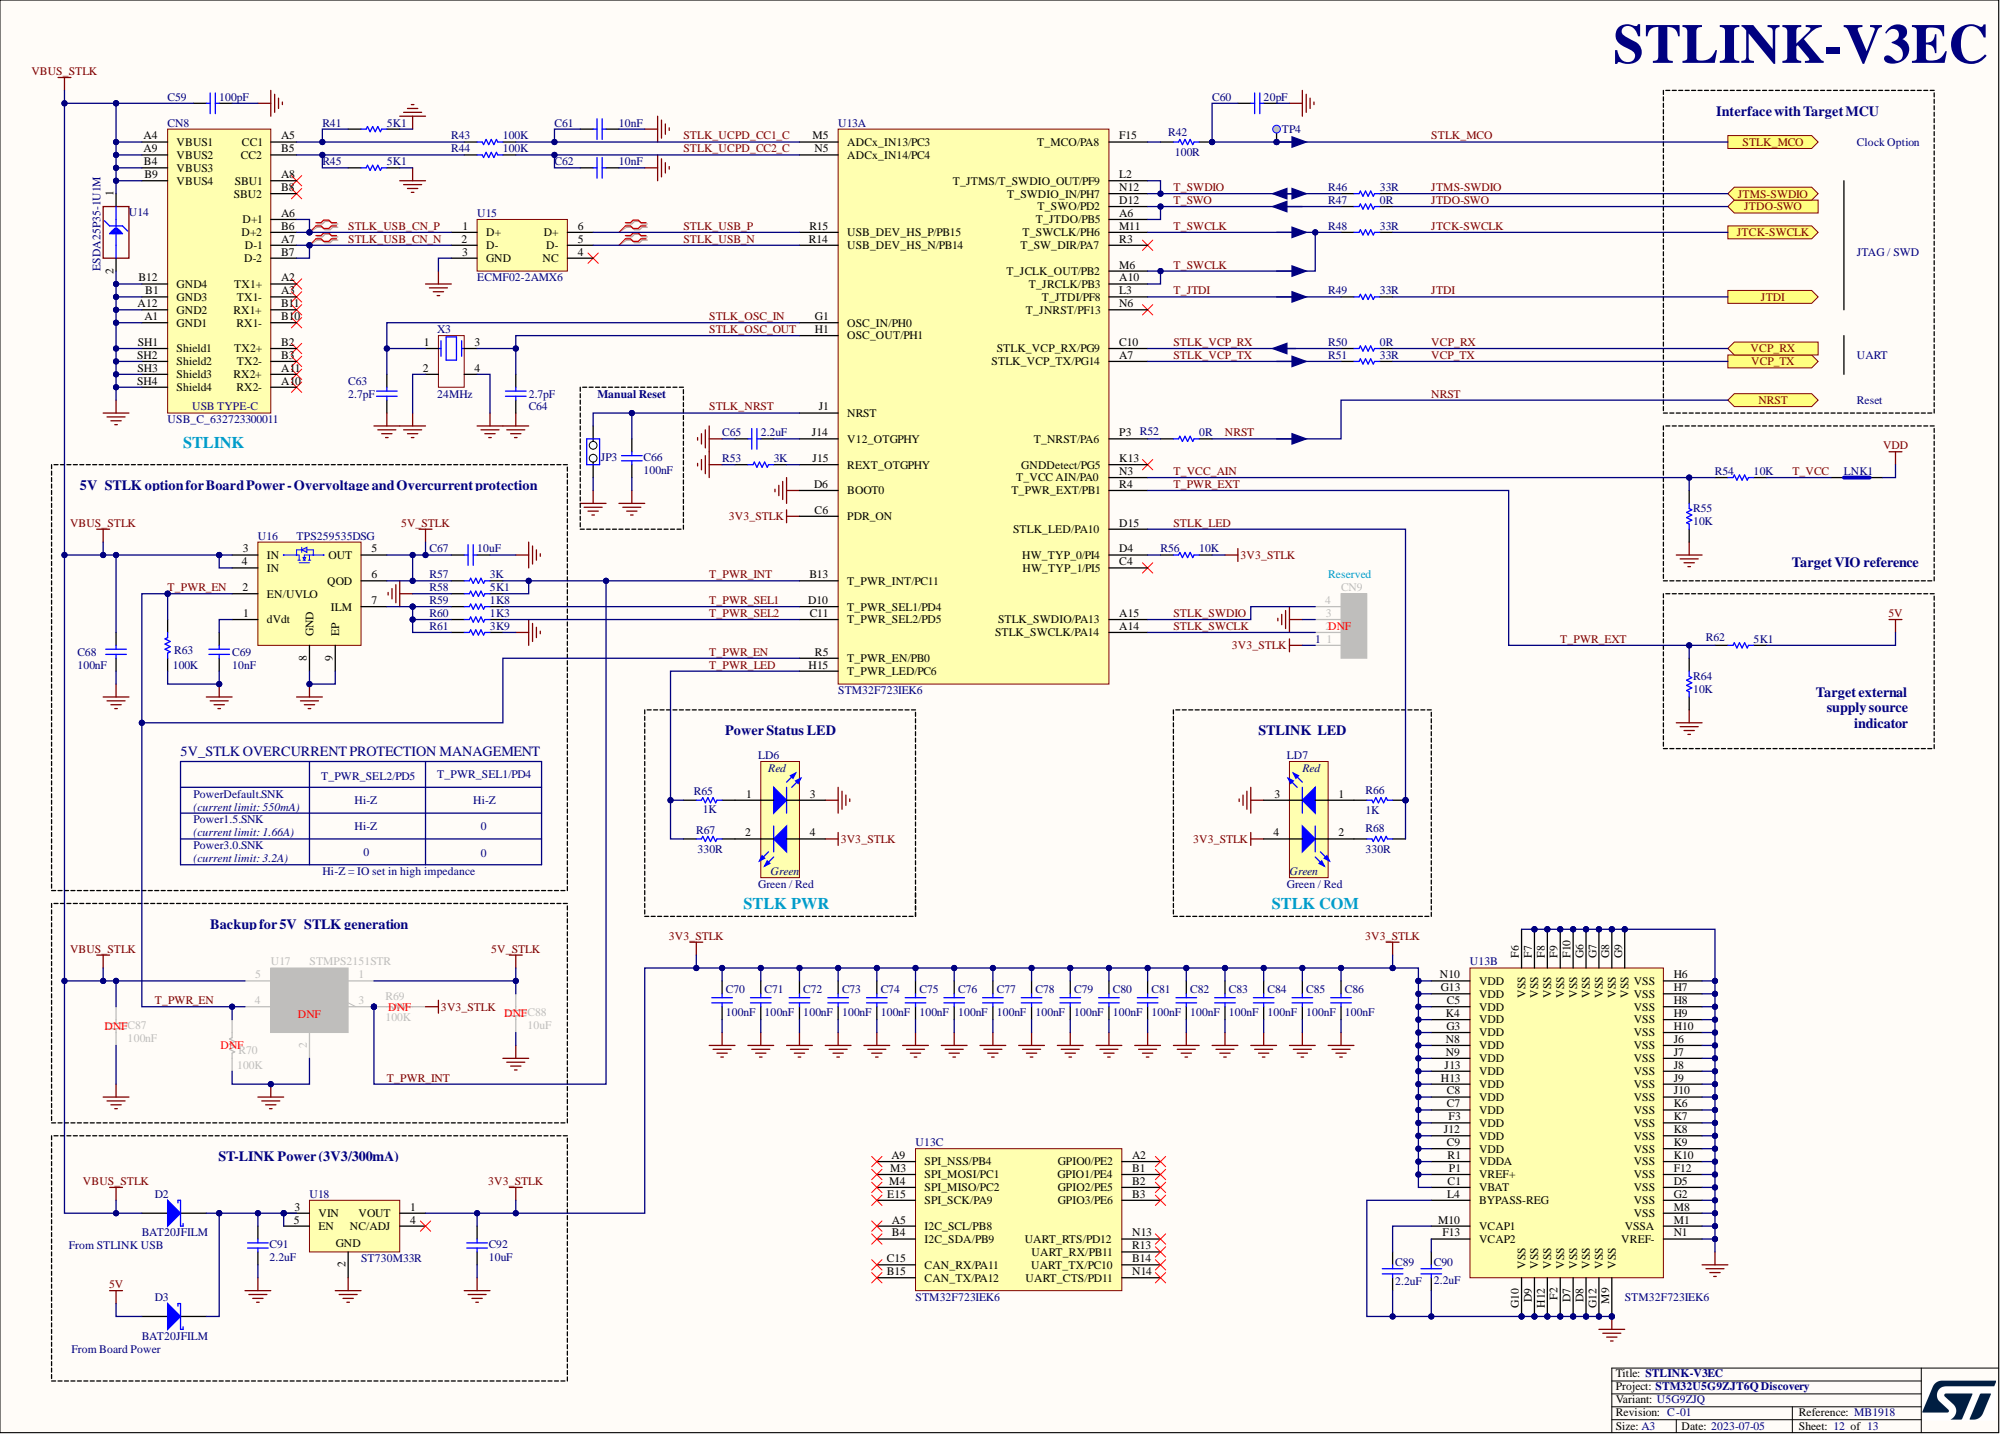
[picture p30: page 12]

VBUS2 A9 | R44 100K STLK_UCPD_CC2_C | ADCx_IN14/PC4 N5

V12_OTGPHY J14

5V_STLK option forBoardPower - Overvoltage andOvercurrent protection

C68 | T_PWR_EN | IN 4 | R57 3K

Reserved CN9

R58 5K1 | | T_PWR_SEL1 | T_PWR_SEL1/PD4 D10
R60 | 1K3 | T_PWR_SEL2 | T_PWR_SEL2/PD5 C11 | | | 1 1 2 2 3 3 4 4

R61 | 3K9 | | T_PWR_EN | T_PWR_EN/PB0 R5 | | STLK_SWCLK | DNF

PowerDefault.SNK (current limit: 550mA) | Hi-Z | Hi-Z

Power1.5.SNK (current limit: 1.66A) | Hi-Z | 0

Hi-Z = IO set in high impedance

VSS M9 VSS G12 VSS D8 VSS D7 VSS F2 VSS H12 VSS D9 VSS F6

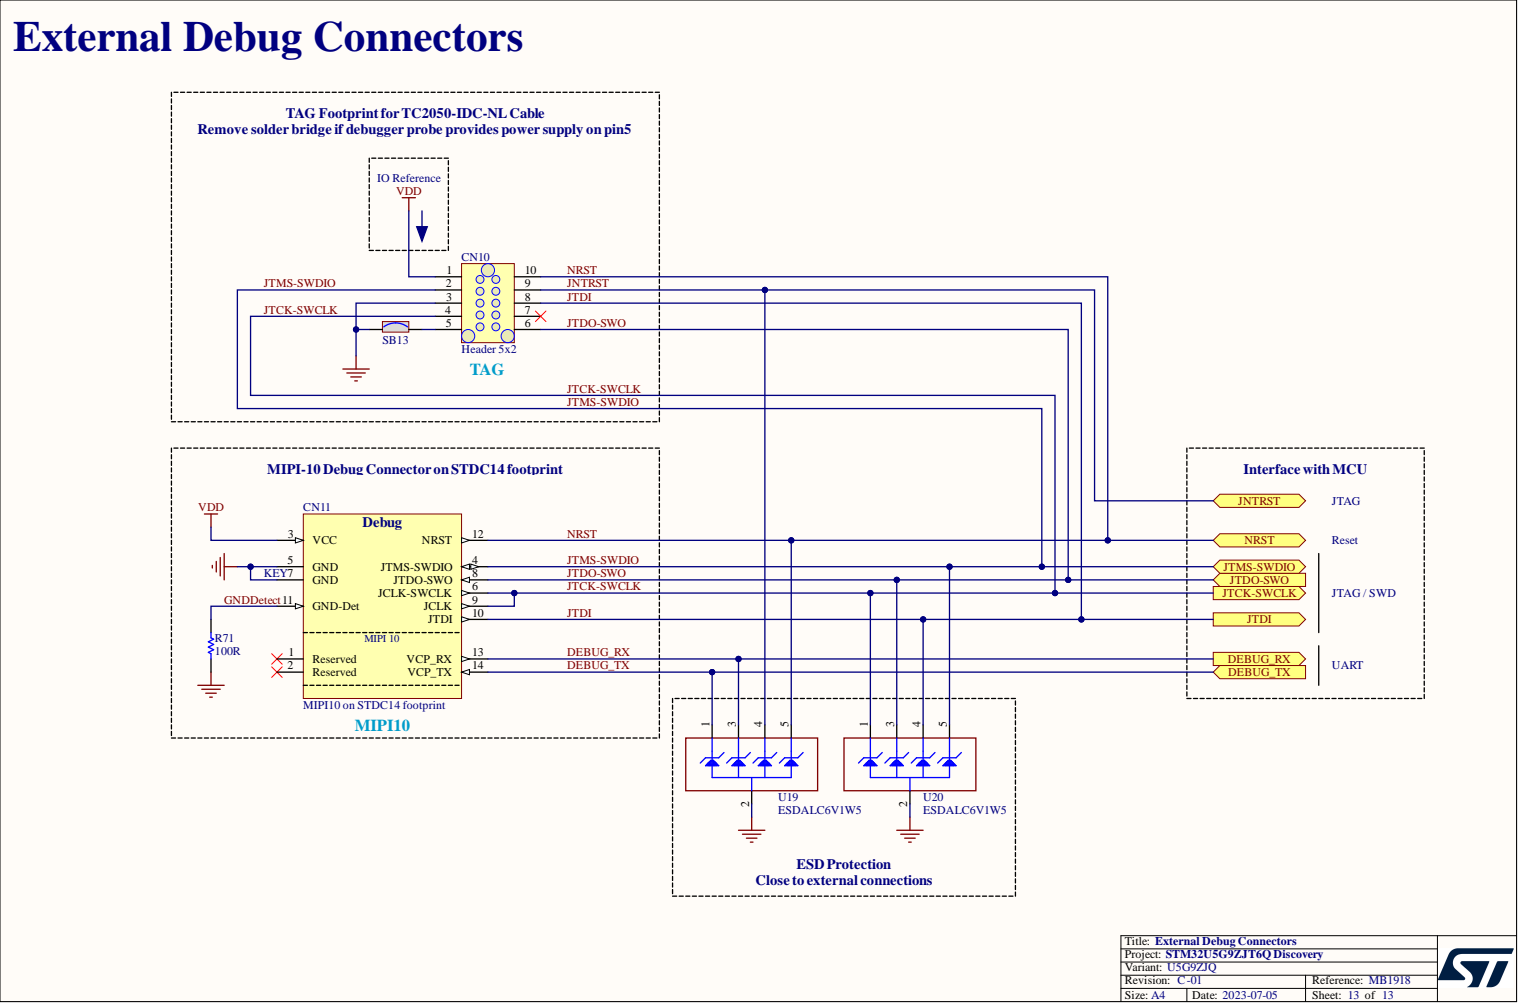
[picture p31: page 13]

TAG Footprint forTC2050-IDC-NL Cable

Remove solder bridge if debugger probe provides power supply on pin5

JNTRST

3 | | 8 | JTDI
5 | 6 | JTDO-SWO

MIPI-10 Debug Connector on STDC14 footprint

JTMS-SWDIO

KEY | JCLK-SWCLK JTDO-SWO | 6 GND 7 8 | JTDO-SWO

JTCK-SWCLK

JTDI MIPI 10 VCP_RX VCP_TX | 10 JCLK 9 GND-Det 11 | | JTDI

13 DEBUG_RX

Reserved 2 | 14 DEBUG_TX

Close to external connections

Title: External Debug Connectors











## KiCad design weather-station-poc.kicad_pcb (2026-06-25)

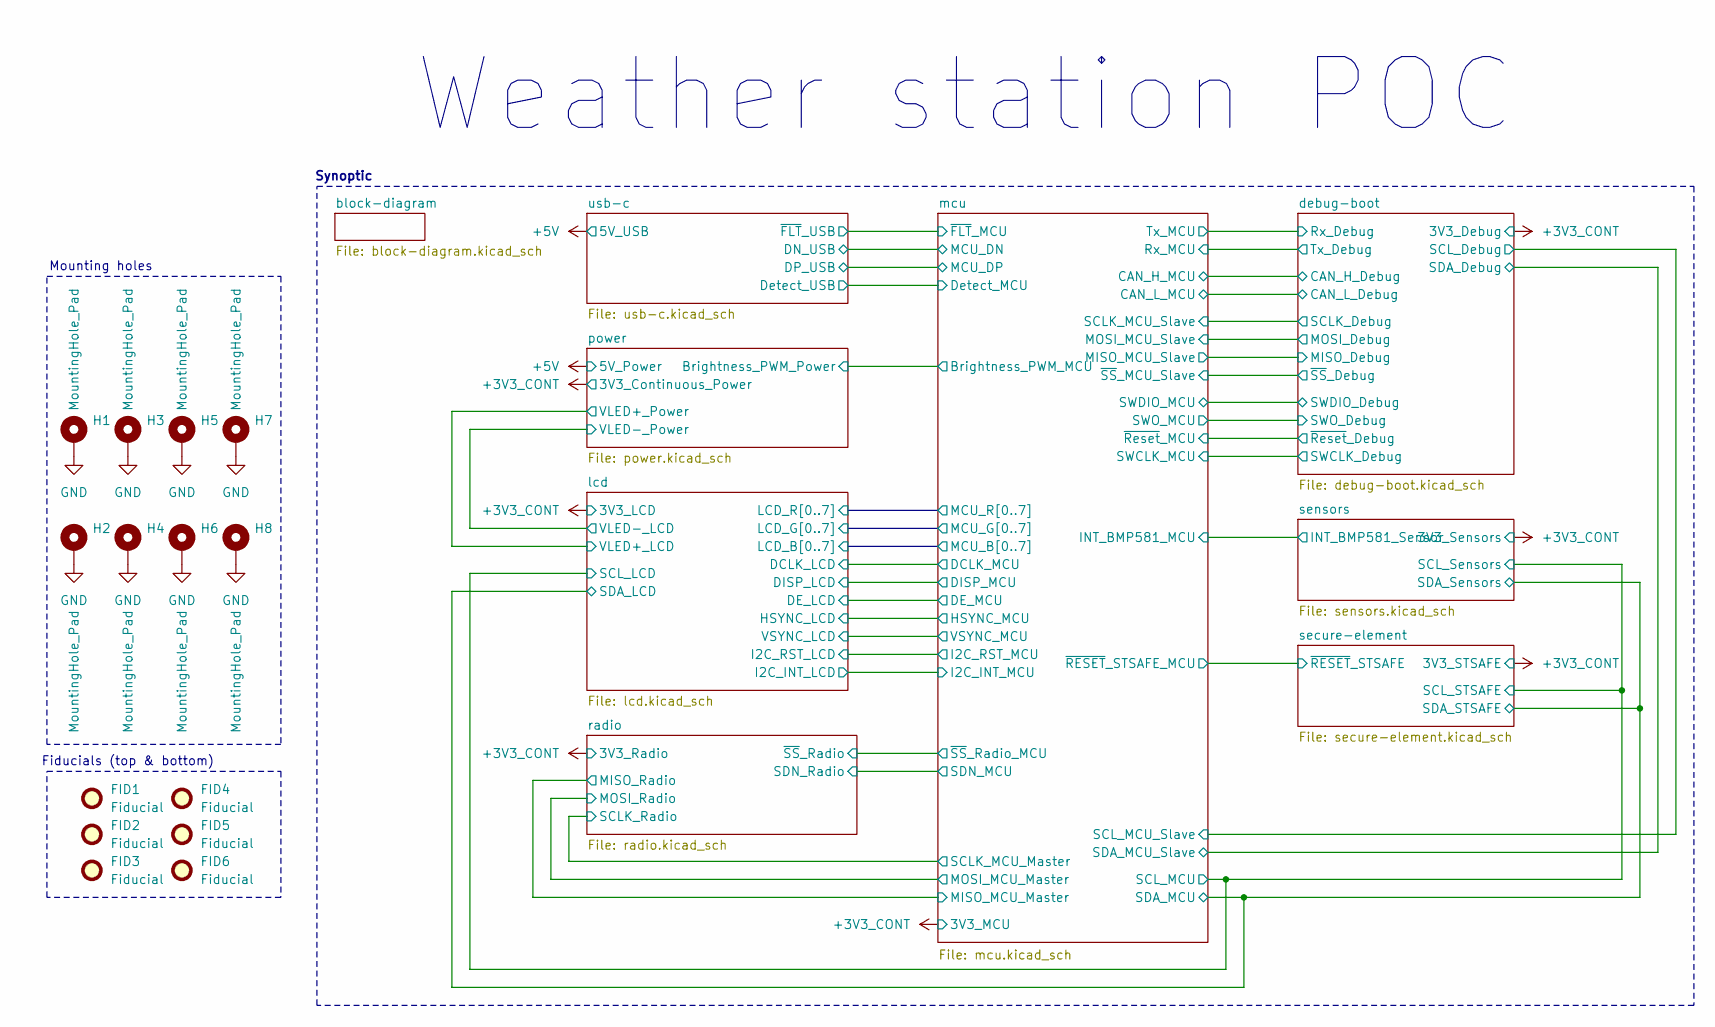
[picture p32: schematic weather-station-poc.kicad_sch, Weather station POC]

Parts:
FID1, FID2, FID3, FID4, FID5, FID6: Fiducial; Fiducial_1mm_Mask2mm; Manufacturer_Part_Number N/A
H1, H2, H3, H4, H5, H6, H7, H8: MountingHole_Pad; MountingHole_3.5mm_Pad_Via; Manufacturer_Part_Number N/A

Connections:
GND: H1.1 (1_1), H2.1 (1_1), H3.1 (1_1), H4.1 (1_1), H5.1 (1_1), H6.1 (1_1), H7.1 (1_1), H8.1 (1_1); also elsewhere on the board

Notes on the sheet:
Weather station POC
Synoptic
Fiducials (top & bottom)
Mounting holes

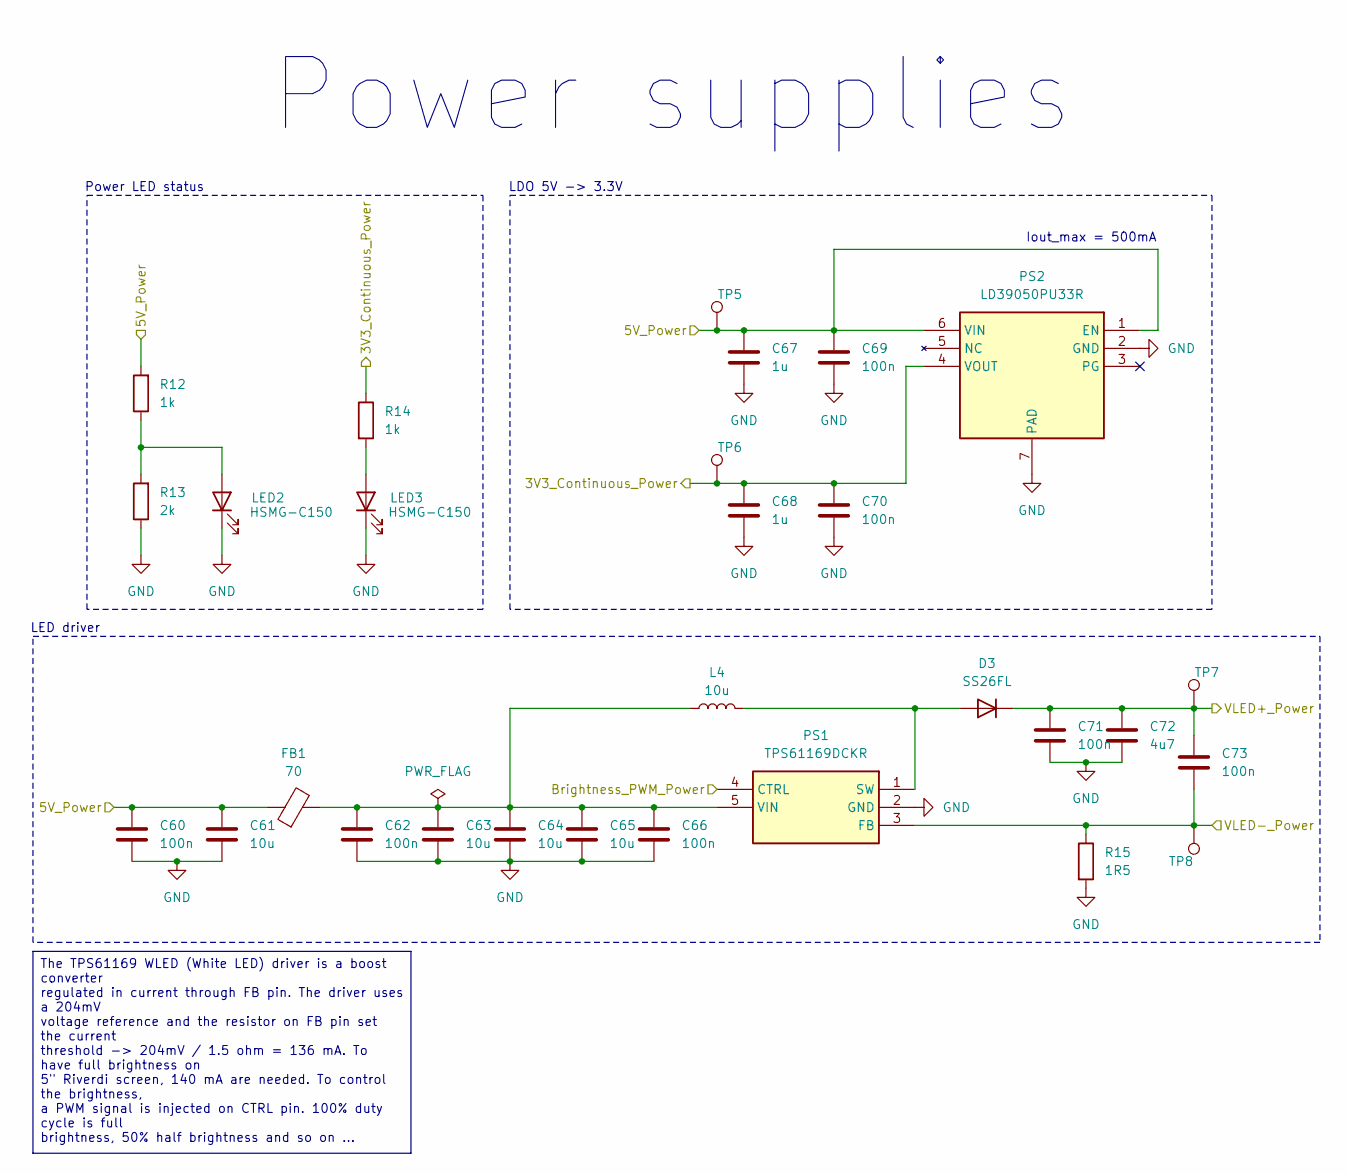
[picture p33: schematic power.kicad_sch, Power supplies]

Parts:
C60, C62, C66, C69, C70, C71, C73: 100n; C_0603_1608Metric_Pad1.08x0.95mm_HandSolder; Manufacturer_Part_Number 885012206020
C61, C63, C64, C65: 10u; C_0603_1608Metric_Pad1.08x0.95mm_HandSolder; Manufacturer_Part_Number GRM188Z71A106KA73D
C67, C68: 1u; C_0603_1608Metric_Pad1.08x0.95mm_HandSolder; Manufacturer_Part_Number 885012206026
C72: 4u7; C_0603_1608Metric_Pad1.08x0.95mm_HandSolder; Manufacturer_Part_Number GRM188Z71A475KE15J
D3: SS26FL; SODFL3617X108N; Mouser Part Number 512-SS26FL
FB1: 70; L_0603_1608Metric_Pad1.05x0.95mm_HandSolder; Part number BLM18SG700TN1D
L4: 10u; INDPM4040X180N; Manufacturer_Part_Number 74404042100
LED2, LED3: HSMG-C150; LEDC3216X120N; Mouser Part Number 630-HSMG-C150
PS1: TPS61169DCKR; SOT65P210X110-5N; Mouser Part Number 595-TPS61169DCKR
PS2: LD39050PU33R; SON95P300X300X100-7N-D; Mouser Part Number 511-LD39050PU33R
R12, R14: 1k; R_0603_1608Metric_Pad0.98x0.95mm_HandSolder; Manufacturer_Part_Number 560112116014
R13: 2k; R_0603_1608Metric_Pad0.98x0.95mm_HandSolder; Manufacturer_Part_Number 560112116058
R15: 1R5; R_0603_1608Metric_Pad0.98x0.95mm_HandSolder; Manufacturer_Part_Number ERJ-H3QD1R50V
TP5, TP6, TP7, TP8: TestPoint; 5015; Manufacturer_Part_Number N/A

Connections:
+3V3_CONT: C68.1, C70.1, PS2.4 (VOUT), R14.1, TP6.1 (1_1); also elsewhere on the board
+5V: C60.1, C61.1, C67.1, C69.1, FB1.1, PS2.1 (EN), PS2.6 (VIN), R12.2, TP5.1 (1_1); also elsewhere on the board
/lcd/VLED+_LCD: C71.1, C72.1, C73.1, D3.1 (K), TP7.1 (1_1); also elsewhere on the board
/lcd/VLED-_LCD: C73.2, PS1.3 (FB), R15.1, TP8.1 (1_1); also elsewhere on the board
/mcu/Brightness_PWM_MCU: PS1.4 (CTRL); also elsewhere on the board
GND: C60.2, C61.2, C62.2, C63.2, C64.2, C65.2, C66.2, C67.2, C68.2, C69.2, C70.2, C71.2, C72.2, LED2.1 (K), LED3.1 (K), PS1.2 (GND), PS2.2 (GND), PS2.7 (PAD), R13.1, R15.2; also elsewhere on the board
unnamed: D3.2 (A), L4.2, PS1.1 (SW)
unnamed: LED2.2 (A), R12.1, R13.2
unnamed: LED3.2 (A), R14.2
unnamed: C62.1, C63.1, C64.1, C65.1, C66.1, FB1.2, L4.1, PS1.5 (VIN)

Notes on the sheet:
Power supplies
LED driver
LDO 5V -> 3.3V
Iout_max = 500mA
Power LED status
The TPS61169 WLED (White LED) driver is a boost converter regulated in current through FB pin. The driver uses a 204mV voltage reference and the resistor on FB pin set the current threshold -> 204mV / 1.5 ohm = 136 mA. To have full brightness on 5" Riverdi screen, 140 mA are needed. To control the 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

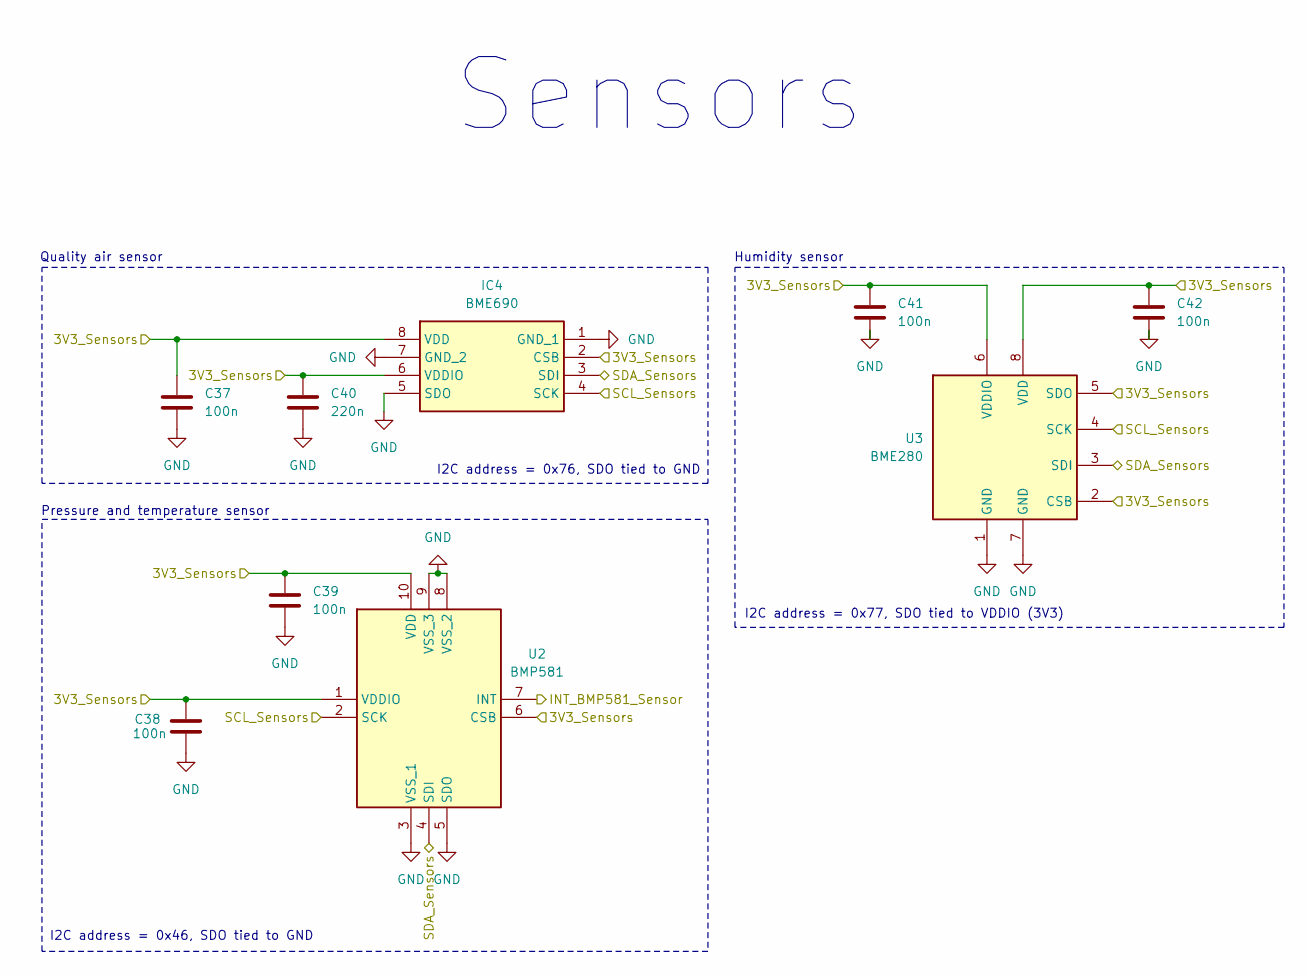
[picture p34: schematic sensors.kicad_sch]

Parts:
C37, C38, C39, C41, C42: 100n; C_0603_1608Metric_Pad1.08x0.95mm_HandSolder; Manufacturer_Part_Number 885012206020
C40: 220n; C_0603_1608Metric_Pad1.08x0.95mm_HandSolder; Manufacturer_Part_Number 885012206022
IC4: BME690; Mouser Part Number 262-BME690
U2: BMP581; Mouser Part Number 262-BMP581
U3: BME280; Bosch_LGA-8_2.5x2.5mm_P0.65mm_ClockwisePinNumbering; Manufacturer_Part_Number BME280

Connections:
+3V3_CONT: C37.1, C38.1, C39.1, C40.1, C41.1, C42.1, IC4.2 (CSB), IC4.6 (VDDIO), IC4.8 (VDD), U2.1 (VDDIO), U2.6 (CSB), U2.10 (VDD), U3.2 (CSB), U3.5 (SDO), U3.6 (VDDIO), U3.8 (VDD); also elsewhere on the board
/lcd/SCL_LCD: IC4.4 (SCK), U2.2 (SCK), U3.4 (SCK); also elsewhere on the board
/lcd/SDA_LCD: IC4.3 (SDI), U2.4 (SDI), U3.3 (SDI); also elsewhere on the board
/mcu/INT_BMP581_MCU: U2.7 (INT); also elsewhere on the board
GND: C37.2, C38.2, C39.2, C40.2, C41.2, C42.2, IC4.1 (GND_1), IC4.5 (SDO), IC4.7 (GND_2), U2.3 (VSS_1), U2.5 (SDO), U2.8 (VSS_2), U2.9 (VSS_3), U3.1 (GND), U3.7 (GND); also elsewhere on the board

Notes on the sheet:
I2C address = 0x77, SDO tied to VDDIO (3V3)
Humidity sensor
Pressure and temperature sensor
I2C address = 0x46, SDO tied to GND
Sensors
Quality air sensor
I2C address = 0x76, SDO tied to GND

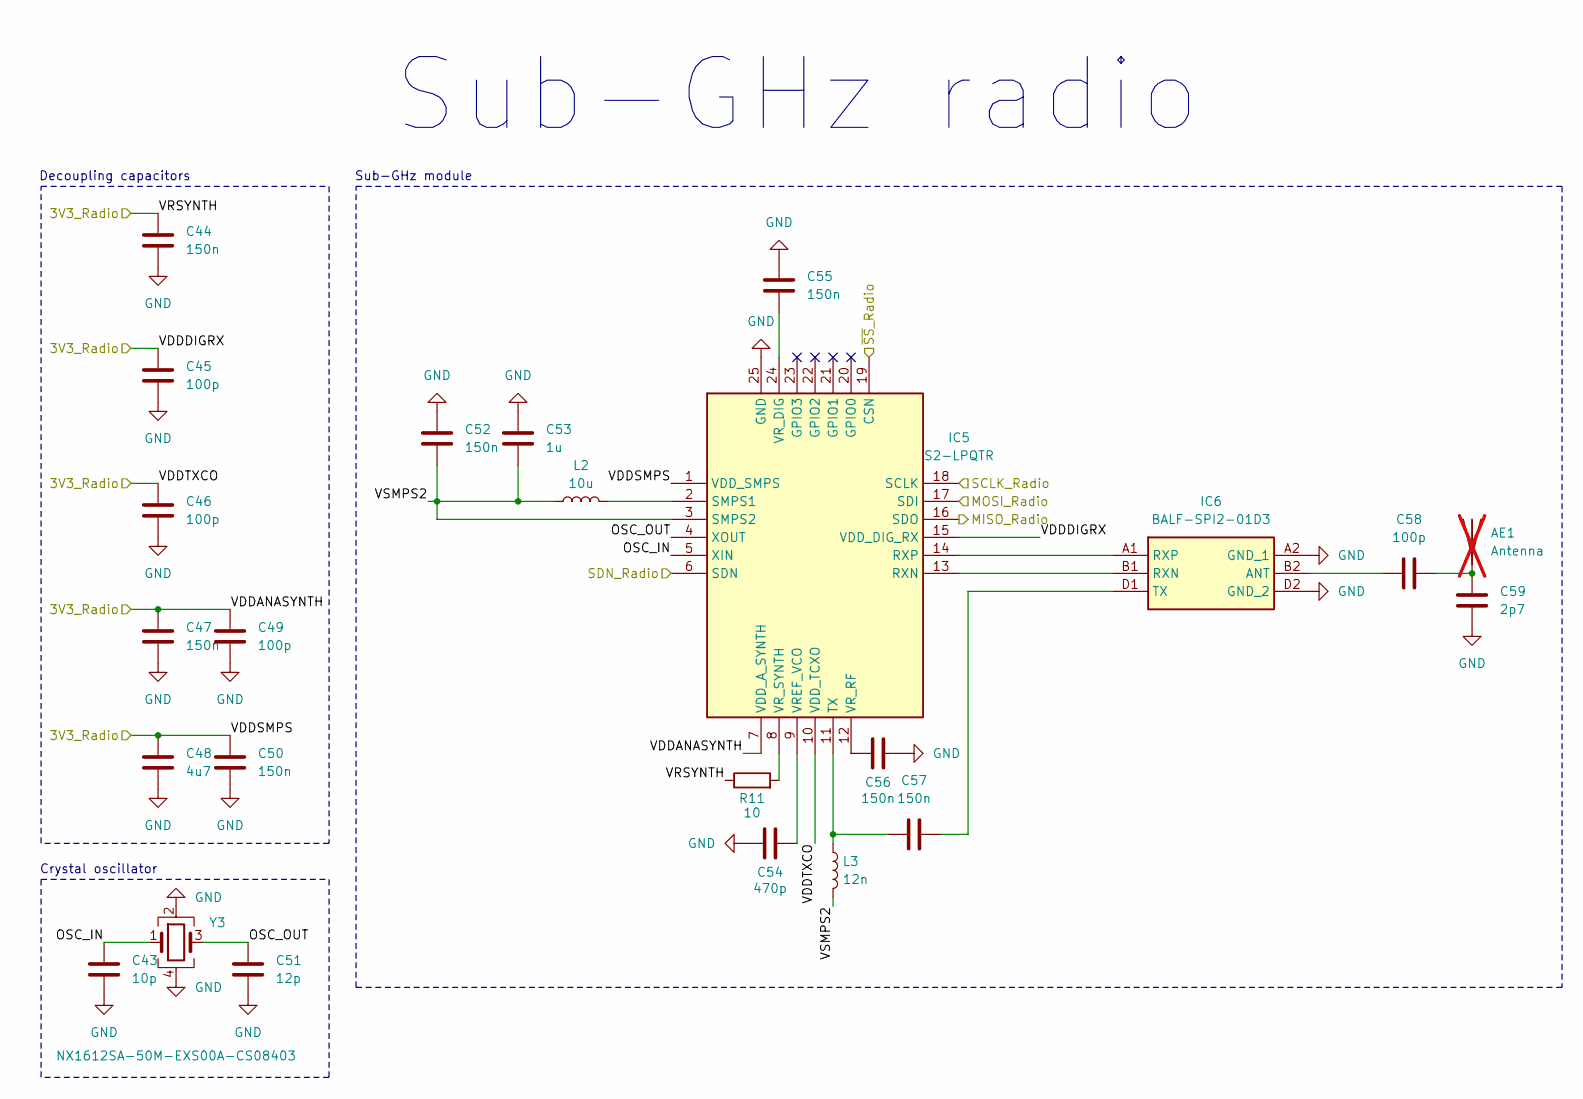
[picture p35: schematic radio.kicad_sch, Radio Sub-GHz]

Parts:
AE1: Antenna; SMA_Molex_73251-1153_EdgeMount_Horizontal; Manufacturer_Part_Number 73251-1153; not fitted
C43: 10p; C_0603_1608Metric_Pad1.08x0.95mm_HandSolder; Manufacturer_Part_Number 885012006002
C44, C47, C50, C52, C55, C56, C57: 150n; C_0603_1608Metric_Pad1.08x0.95mm_HandSolder; Manufacturer_Part_Number 885012206021
C45, C46, C49, C58: 100p; C_0603_1608Metric_Pad1.08x0.95mm_HandSolder; Manufacturer_Part_Number 885012206003
C48: 4u7; C_0603_1608Metric_Pad1.08x0.95mm_HandSolder; Manufacturer_Part_Number GRM188Z71A475KE15J
C51: 12p; C_0603_1608Metric_Pad1.08x0.95mm_HandSolder; Manufacturer_Part_Number VJ0603A120FXQCW1BC
C53: 1u; C_0603_1608Metric_Pad1.08x0.95mm_HandSolder; Manufacturer_Part_Number 885012206026
C54: 470p; C_0603_1608Metric_Pad1.08x0.95mm_HandSolder; Manufacturer_Part_Number 885012206006
C59: 2p7; C_0603_1608Metric_Pad1.08x0.95mm_HandSolder; Manufacturer_Part_Number VJ0603A2R7BXQCW1BC
IC5: S2-LPQTR; QFN50P400X400X100-25N-D; Mouser Part Number 511-S2-LPQTR
IC6: BALF-SPI2-01D3; BALFSPI201D3; Mouser Part Number 511-BALF-SPI2-01D3
L2: 10u; L_0805_2012Metric_Pad1.05x1.20mm_HandSolder; Manufacturer_Part_Number LQM21FN100M80L
L3: 12n; L_0603_1608Metric_Pad1.05x0.95mm_HandSolder; Manufacturer_Part_Number LQW18AN12NG00D
R11: 10; R_0603_1608Metric_Pad0.98x0.95mm_HandSolder; Manufacturer_Part_Number 560050316012
Y3: NX1612SA-50M-EXS00A-CS08403; NX1612SA50MEXS00ACS08403; Mouser Part Number 344-NX1612SA50S08403

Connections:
+3V3_CONT: C44.1, C45.1, C46.1, C47.1, C48.1, C49.1, C50.1, IC5.1 (VDD_SMPS), IC5.7 (VDD_A_SYNTH), IC5.10 (VDD_TCXO), IC5.15 (VDD_DIG_RX), R11.1; also elsewhere on the board
/mcu/MISO_MCU_Master: IC5.16 (SDO); also elsewhere on the board
/mcu/MOSI_MCU_Master: IC5.17 (SDI); also elsewhere on the board
/mcu/SCLK_MCU_Master: IC5.18 (SCLK); also elsewhere on the board
/mcu/SDN_MCU: IC5.6 (SDN); also elsewhere on the board
/mcu/~SS_Radio_MCU: IC5.19 (CSN); also elsewhere on the board
/radio/OSC_IN: C43.1, IC5.5 (XIN), Y3.1
/radio/OSC_OUT: C51.2, IC5.4 (XOUT), Y3.3
/radio/VSMPS2: C52.1, C53.1, IC5.3 (SMPS2), L2.1, L3.2
GND: C43.2, C44.2, C45.2, C46.2, C47.2, C48.2, C49.2, C50.2, C51.1, C52.2, C53.2, C54.1, C55.2, C56.2, C59.1, IC5.25 (GND), IC6.A2 (GND_1), IC6.D2 (GND_2), Y3.2, Y3.4; also elsewhere on the board
unnamed: AE1.1 (A_1), C58.1, C59.2
unnamed: IC5.13 (RXN), IC6.B1 (RXN)
unnamed: IC5.14 (RXP), IC6.A1 (RXP)
unnamed: IC5.2 (SMPS1), L2.2
unnamed: C57.1, IC5.11 (TX), L3.1
unnamed: C54.2, IC5.9 (VREF_VCO)
unnamed: C55.1, IC5.24 (VR_DIG)
unnamed: C56.1, IC5.12 (VR_RF)
unnamed: IC5.8 (VR_SYNTH), R11.2
unnamed: C58.2, IC6.B2 (ANT)
unnamed: C57.2, IC6.D1 (TX)

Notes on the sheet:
Sub-GHz radio
Decoupling capacitors
Sub-GHz module
Crystal oscillator

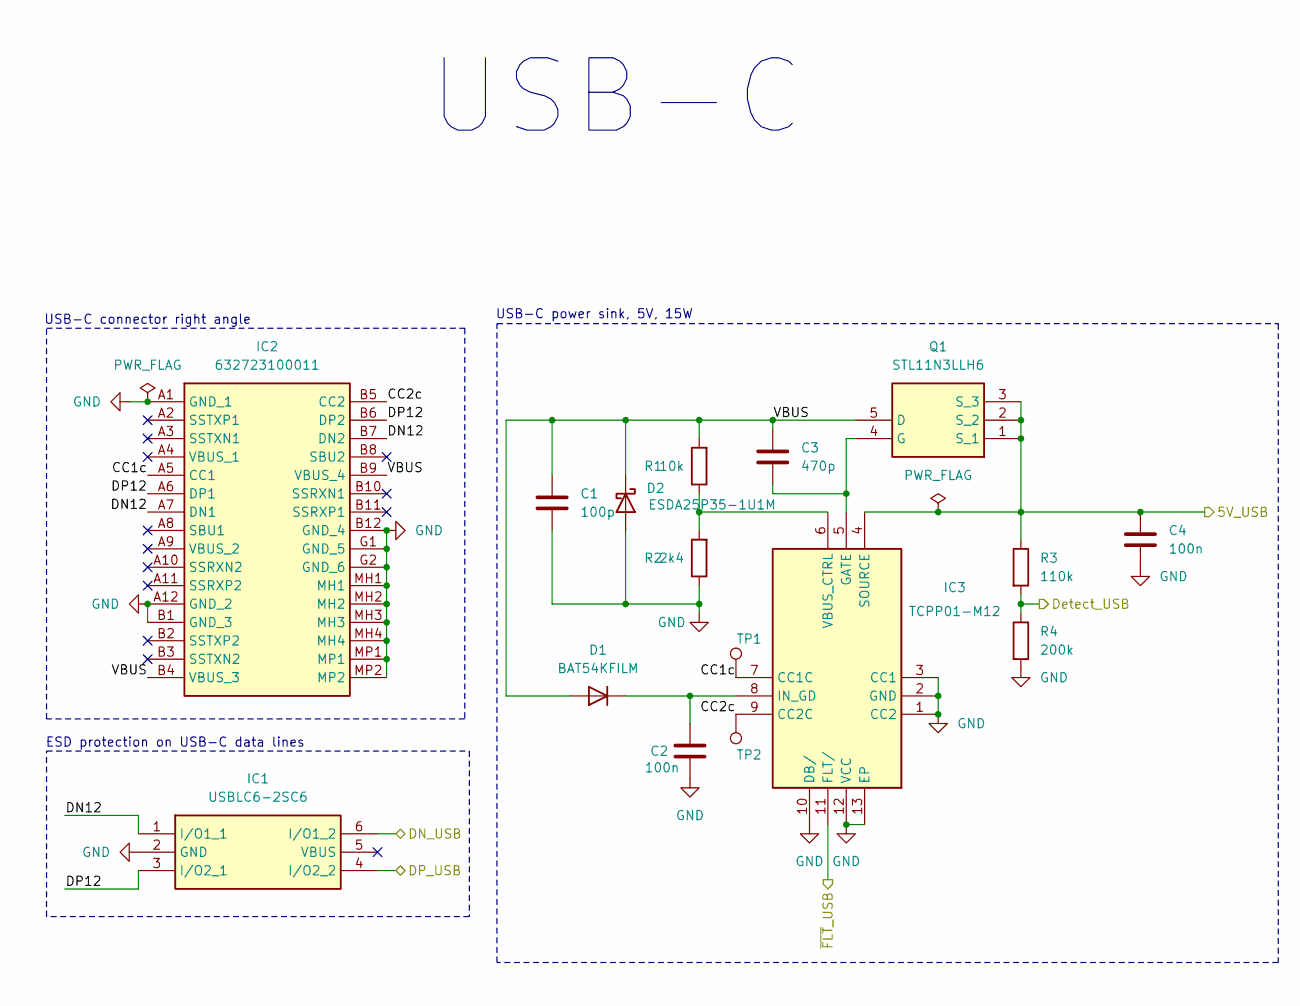
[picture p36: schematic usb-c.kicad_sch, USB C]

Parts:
C1: 100p; C_0603_1608Metric_Pad1.08x0.95mm_HandSolder; Manufacturer_Part_Number 885012206003
C2, C4: 100n; C_0603_1608Metric_Pad1.08x0.95mm_HandSolder; Manufacturer_Part_Number 885012206020
C3: 470p; C_0603_1608Metric_Pad1.08x0.95mm_HandSolder; Manufacturer_Part_Number 885012206006
D1: BAT54KFILM; SODFL1608X70N; Mouser Part Number 511-BAT54KFILM
D2: ESDA25P35-1U1M; ESDA25P351U1M; Mouser Part Number 511-ESDA25P35-1U1M
IC1: USBLC6-2SC6; SOT95P280X145-6N; Manufacturer_Part_Number USBLC6-2SC6; Mouser Part Number 511-USBLC6-2SC6
IC2: 632723100011; Mouser Part Number 710-632723100011
IC3: TCPP01-M12; QFN50P300X300X100-13N-D; Manufacturer_Part_Number TCPP01-M12; Mouser Part Number 511-TCPP01-M12
Q1: STL11N3LLH6; STL20N6F7; Manufacturer_Part_Number STL11N3LLH6; Mouser Part Number 511-STL11N3LLH6
R1: 10k; R_0603_1608Metric_Pad0.98x0.95mm_HandSolder; Manufacturer_Part_Number 560112116005
R2: 2k4; R_0603_1608Metric_Pad0.98x0.95mm_HandSolder; Manufacturer_Part_Number 560112116061
R3: 110k; R_0603_1608Metric_Pad0.98x0.95mm_HandSolder; Manufacturer_Part_Number 560112116148
R4: 200k; R_0603_1608Metric_Pad0.98x0.95mm_HandSolder; Manufacturer_Part_Number 560112116060
TP1, TP2: TestPoint; 5015; Manufacturer_Part_Number N/A

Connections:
+5V: C4.1, IC3.4 (SOURCE), Q1.1 (S_1), Q1.2 (S_2), Q1.3 (S_3), R3.1; also elsewhere on the board
/mcu/Detect_MCU: R3.2, R4.1; also elsewhere on the board
/mcu/MCU_DN: IC1.6 (I/O1_2); also elsewhere on the board
/mcu/MCU_DP: IC1.4 (I/O2_2); also elsewhere on the board
/mcu/~FLT_MCU: IC3.11 (FLT/); also elsewhere on the board
/usb-c/CC1c: IC2.A5 (CC1), IC3.7 (CC1C), TP1.1 (1_1)
/usb-c/CC2c: IC2.B5 (CC2), IC3.9 (CC2C), TP2.1 (1_1)
/usb-c/DN12: IC1.1 (I/O1_1), IC2.A7 (DN1), IC2.B7 (DN2)
/usb-c/DP12: IC1.3 (I/O2_1), IC2.A6 (DP1), IC2.B6 (DP2)
/usb-c/VBUS: C1.1, C3.1, D1.2 (A), D2.1 (K), IC2.B4 (VBUS_3), IC2.B9 (VBUS_4), Q1.5 (D), R1.2
GND: C1.2, C2.2, C4.2, D2.2 (A), IC1.2 (GND), IC2.A1 (GND_1), IC2.A12 (GND_2), IC2.B1 (GND_3), IC2.B12 (GND_4), IC2.G1 (GND_5), IC2.G2 (GND_6), IC2.MH1, IC2.MH2, IC2.MH3, IC2.MH4, IC2.MP1, IC2.MP2, IC3.1 (CC2), IC3.2 (GND), IC3.3 (CC1), IC3.10 (DB/), IC3.12 (VCC), IC3.13 (EP), R2.1, R4.2; also elsewhere on the board
unnamed: C2.1, D1.1 (K), IC3.8 (IN_GD)
unnamed: C3.2, IC3.5 (GATE), Q1.4 (G)
unnamed: IC3.6 (VBUS_CTRL), R1.1, R2.2

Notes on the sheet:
USB-C connector right angle
USB-C
ESD protection on USB-C data lines
USB-C power sink, 5V, 15W

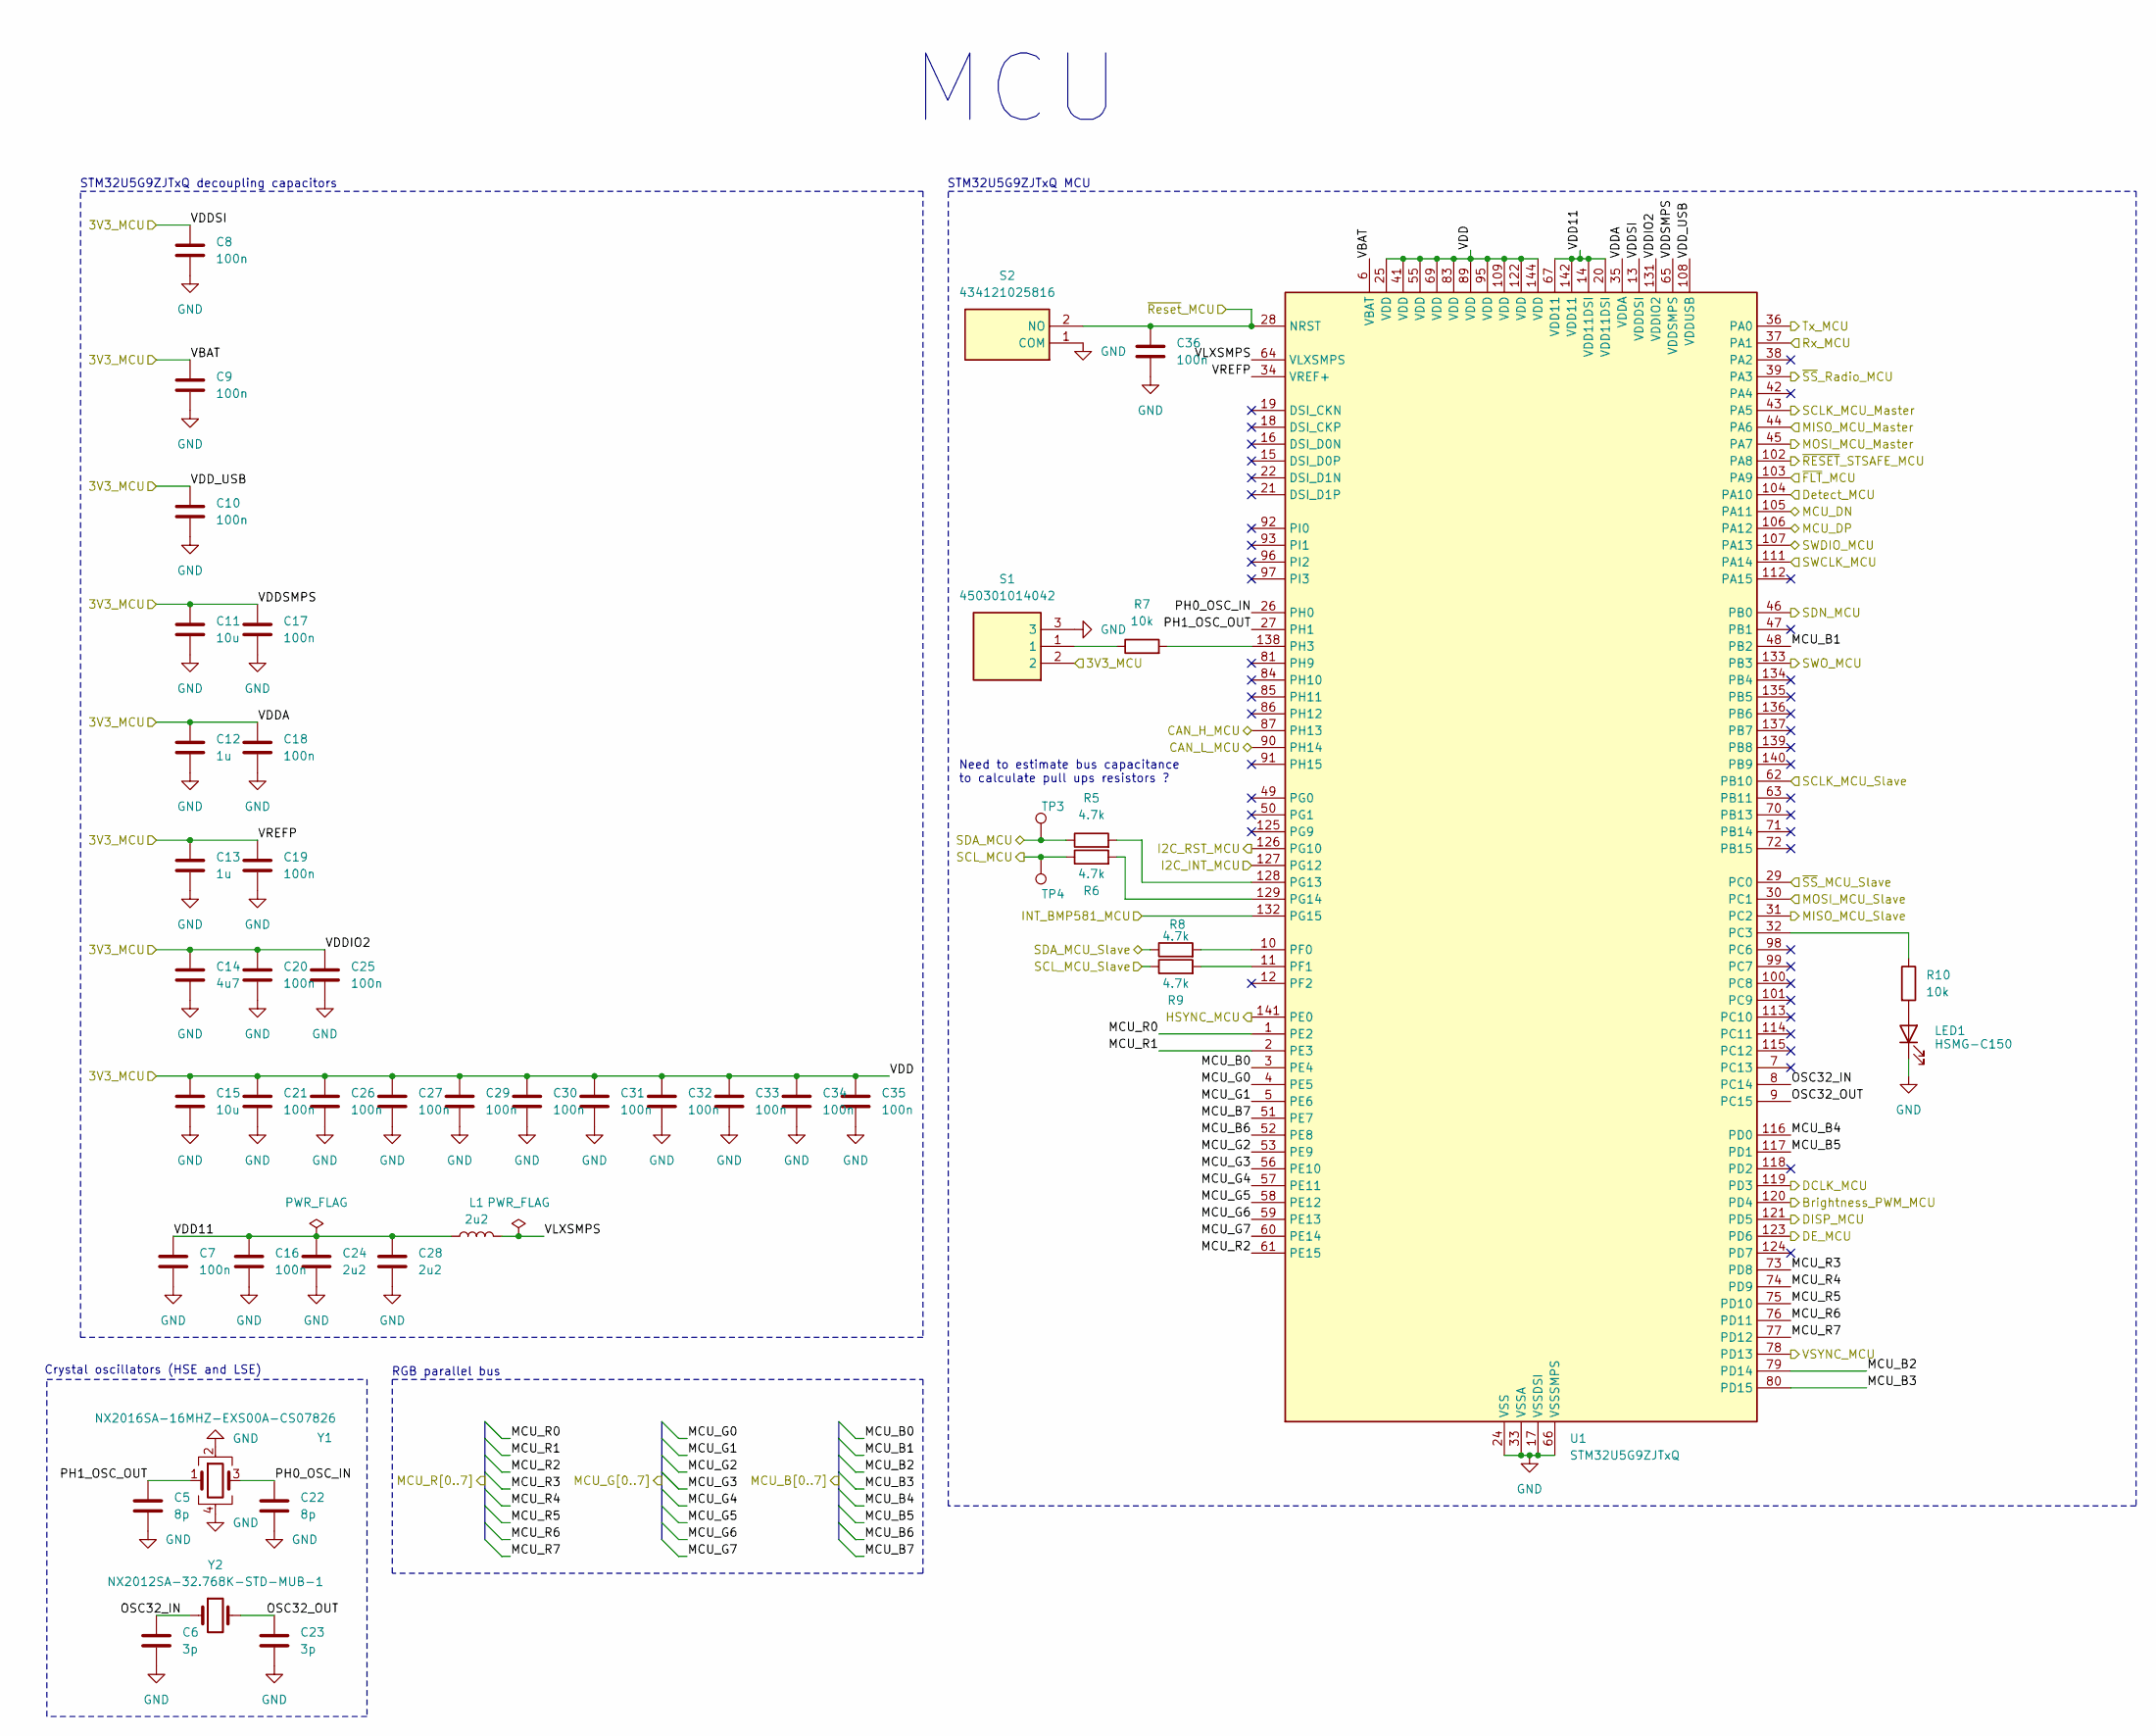
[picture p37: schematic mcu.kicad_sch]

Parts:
C5, C22: 8p; C_0402_1005Metric_Pad0.74x0.62mm_HandSolder; Manufacturer_Part_Number CC0402CRNPO9BN8R2
C6, C23: 3p; C_0402_1005Metric_Pad0.74x0.62mm_HandSolder; Manufacturer_Part_Number CC0402BRNPO9BN3R3
C7, C8, C9, C10, C16, C17, C18, C19, C20, C21, C25, C26, C27, C29, C30, C31, C32, C33, C34, C35, C36: 100n; C_0603_1608Metric_Pad1.08x0.95mm_HandSolder; Manufacturer_Part_Number 885012206020
C11, C15: 10u; C_0603_1608Metric_Pad1.08x0.95mm_HandSolder; Manufacturer_Part_Number GRM188Z71A106KA73D
C12, C13: 1u; C_0603_1608Metric_Pad1.08x0.95mm_HandSolder; Manufacturer_Part_Number 885012206026
C14: 4u7; C_0603_1608Metric_Pad1.08x0.95mm_HandSolder; Manufacturer_Part_Number GRM188Z71A475KE15J
C24, C28: 2u2; C_0603_1608Metric_Pad1.08x0.95mm_HandSolder; Manufacturer_Part_Number 885012206027
L1: 2u2; L_0805_2012Metric_Pad1.05x1.20mm_HandSolder; Manufacturer_Part_Number LQM21PN2R2MGHL
LED1: HSMG-C150; LEDC3216X120N; Mouser Part Number 630-HSMG-C150
R5, R6, R8, R9: 4.7k; R_0603_1608Metric_Pad0.98x0.95mm_HandSolder; Manufacturer_Part_Number 560112116006
R7, R10: 10k; R_0603_1608Metric_Pad0.98x0.95mm_HandSolder; Manufacturer_Part_Number 560112116005
S1: 450301014042; Mouser Part Number 710-450301014042
S2: 434121025816; 434121050816; Mouser Part Number 710-434121025816
TP3, TP4: TestPoint; 5015; Manufacturer_Part_Number N/A
U1: STM32U5G9ZJTxQ; LQFP-144_20x20mm_P0.5mm; Manufacturer_Part_Number STM32U5G9ZJT6Q
Y1: NX2016SA-16MHZ-EXS00A-CS07826; NX2016SA16MHZEXS00ACS07826; Mouser Part Number 344-MHZEXS00ACS07826
Y2: NX2012SA-32.768K-STD-MUB-1; NX2012SA32768KSTDMUB1; Mouser Part Number 344-NX2012SA32768K1

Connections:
+3V3_CONT: C8.1, C9.1, C10.1, C11.1, C12.1, C13.1, C14.1, C15.1, C17.1, C18.1, C19.1, C20.1, C21.1, C25.1, C26.1, C27.1, C29.1, C30.1, C31.1, C32.1, C33.1, C34.1, C35.1, S1.2, U1.6 (VBAT), U1.13 (VDDDSI), U1.25 (VDD), U1.34 (VREF+), U1.35 (VDDA), U1.41 (VDD), U1.55 (VDD), U1.65 (VDDSMPS), U1.69 (VDD), U1.83 (VDD), U1.89 (VDD), U1.95 (VDD), U1.108 (VDDUSB), U1.109 (VDD), U1.122 (VDD), U1.131 (VDDIO2), U1.144 (VDD); also elsewhere on the board
/debug-boot/CAN_H_Debug: U1.87 (PH13); also elsewhere on the board
/debug-boot/CAN_L_Debug: U1.90 (PH14); also elsewhere on the board
/debug-boot/MISO_Debug: U1.31 (PC2); also elsewhere on the board
/debug-boot/MOSI_Debug: U1.30 (PC1); also elsewhere on the board
/debug-boot/Rx_Debug: U1.36 (PA0); also elsewhere on the board
/debug-boot/SCLK_Debug: U1.62 (PB10); also elsewhere on the board
/debug-boot/SCL_Debug: R9.1; also elsewhere on the board
/debug-boot/SDA_Debug: R8.1; also elsewhere on the board
/debug-boot/SWCLK_Debug: U1.111 (PA14); also elsewhere on the board
/debug-boot/SWDIO_Debug: U1.107 (PA13); also elsewhere on the board
/debug-boot/SWO_Debug: U1.133 (PB3); also elsewhere on the board
/debug-boot/Tx_Debug: U1.37 (PA1); also elsewhere on the board
/debug-boot/~Reset_Debug: C36.1, S2.2 (NO), U1.28 (NRST); also elsewhere on the board
/debug-boot/~SS_Debug: U1.29 (PC0); also elsewhere on the board
/lcd/DCLK_LCD: U1.119 (PD3); also elsewhere on the board
/lcd/DE_LCD: U1.123 (PD6); also elsewhere on the board
/lcd/DISP_LCD: U1.121 (PD5); also elsewhere on the board
/lcd/HSYNC_LCD: U1.141 (PE0); also elsewhere on the board
/lcd/I2C_INT_LCD: U1.127 (PG12); also elsewhere on the board
/lcd/I2C_RST_LCD: U1.126 (PG10); also elsewhere on the board
/lcd/LCD_B0: U1.3 (PE4); also elsewhere on the board
/lcd/LCD_B1: U1.48 (PB2); also elsewhere on the board
/lcd/LCD_B2: U1.79 (PD14); also elsewhere on the board
/lcd/LCD_B3: U1.80 (PD15); also elsewhere on the board
/lcd/LCD_B4: U1.116 (PD0); also elsewhere on the board
/lcd/LCD_B5: U1.117 (PD1); also elsewhere on the board
/lcd/LCD_B6: U1.52 (PE8); also elsewhere on the board
/lcd/LCD_B7: U1.51 (PE7); also elsewhere on the board
/lcd/LCD_G0: U1.4 (PE5); also elsewhere on the board
/lcd/LCD_G1: U1.5 (PE6); also elsewhere on the board
/lcd/LCD_G2: U1.53 (PE9); also elsewhere on the board
/lcd/LCD_G3: U1.56 (PE10); also elsewhere on the board
/lcd/LCD_G4: U1.57 (PE11); also elsewhere on the board
/lcd/LCD_G5: U1.58 (PE12); also elsewhere on the board
/lcd/LCD_G6: U1.59 (PE13); also elsewhere on the board
/lcd/LCD_G7: U1.60 (PE14); also elsewhere on the board
/lcd/LCD_R0: U1.1 (PE2); also elsewhere on the board
/lcd/LCD_R1: U1.2 (PE3); also elsewhere on the board
/lcd/LCD_R2: U1.61 (PE15); also elsewhere on the board
/lcd/LCD_R3: U1.73 (PD8); also elsewhere on the board
/lcd/LCD_R4: U1.74 (PD9); also elsewhere on the board
/lcd/LCD_R5: U1.75 (PD10); also elsewhere on the board
/lcd/LCD_R6: U1.76 (PD11); also elsewhere on the board
/lcd/LCD_R7: U1.77 (PD12); also elsewhere on the board
/lcd/SCL_LCD: R6.1, TP4.1 (1_1); also elsewhere on the board
/lcd/SDA_LCD: R5.1, TP3.1 (1_1); also elsewhere on the board
/lcd/VSYNC_LCD: U1.78 (PD13); also elsewhere on the board
/mcu/Brightness_PWM_MCU: U1.120 (PD4); also elsewhere on the board
/mcu/Detect_MCU: U1.104 (PA10); also elsewhere on the board
/mcu/INT_BMP581_MCU: U1.132 (PG15); also elsewhere on the board
/mcu/MCU_DN: U1.105 (PA11); also elsewhere on the board
/mcu/MCU_DP: U1.106 (PA12); also elsewhere on the board
/mcu/MISO_MCU_Master: U1.44 (PA6); also elsewhere on the board
/mcu/MOSI_MCU_Master: U1.45 (PA7); also elsewhere on the board
/mcu/OSC32_IN: C6.1, U1.8 (PC14), Y2.1
/mcu/OSC32_OUT: C23.1, U1.9 (PC15), Y2.2
/mcu/PH0_OSC_IN: C22.2, U1.26 (PH0), Y1.3
/mcu/PH1_OSC_OUT: C5.2, U1.27 (PH1), Y1.1
/mcu/SCLK_MCU_Master: U1.43 (PA5); also elsewhere on the board
/mcu/SDN_MCU: U1.46 (PB0); also elsewhere on the board
/mcu/VDD11: C7.1, C16.1, C24.1, C28.1, L1.1, U1.14 (VDD11DSI), U1.20 (VDD11DSI), U1.67 (VDD11), U1.142 (VDD11)
/mcu/VLXSMPS: L1.2, U1.64 (VLXSMPS)
/mcu/~FLT_MCU: U1.103 (PA9); also elsewhere on the board
/mcu/~RESET_STSAFE_MCU: U1.102 (PA8); also elsewhere on the board
/mcu/~SS_Radio_MCU: U1.39 (PA3); also elsewhere on the board
GND: C5.1, C6.2, C7.2, C8.2, C9.2, C10.2, C11.2, C12.2, C13.2, C14.2, C15.2, C16.2, C17.2, C18.2, C19.2, C20.2, C21.2, C22.1, C23.2, C24.2, C25.2, C26.2, C27.2, C28.2, C29.2, C30.2, C31.2, C32.2, C33.2, C34.2, C35.2, C36.2, LED1.1 (K), S1.3, S2.1 (COM), U1.17 (VSSDSI), U1.23 (VSSDSI), U1.24 (VSS), U1.33 (VSSA), U1.40 (VSS), U1.54 (VSS), U1.66 (VSSSMPS), U1.68 (VSS), U1.82 (VSS), U1.88 (VSS), U1.94 (VSS), U1.110 (VSS), U1.130 (VSS), U1.143 (VSS), Y1.2, Y1.4; also elsewhere on the board
unnamed: LED1.2 (A), R10.2
unnamed: R7.1, S1.1
unnamed: R10.1, U1.32 (PC3)
unnamed: R8.2, U1.10 (PF0)
unnamed: R9.2, U1.11 (PF1)
unnamed: R5.2, U1.128 (PG13)
unnamed: R6.2, U1.129 (PG14)
unnamed: R7.2, U1.138 (PH3)

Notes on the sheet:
RGB parallel bus
Crystal oscillators (HSE and LSE)
Need to estimate bus capacitance to calculate pull ups resistors ?
STM32U5G9ZJTxQ MCU
MCU
STM32U5G9ZJTxQ decoupling capacitors

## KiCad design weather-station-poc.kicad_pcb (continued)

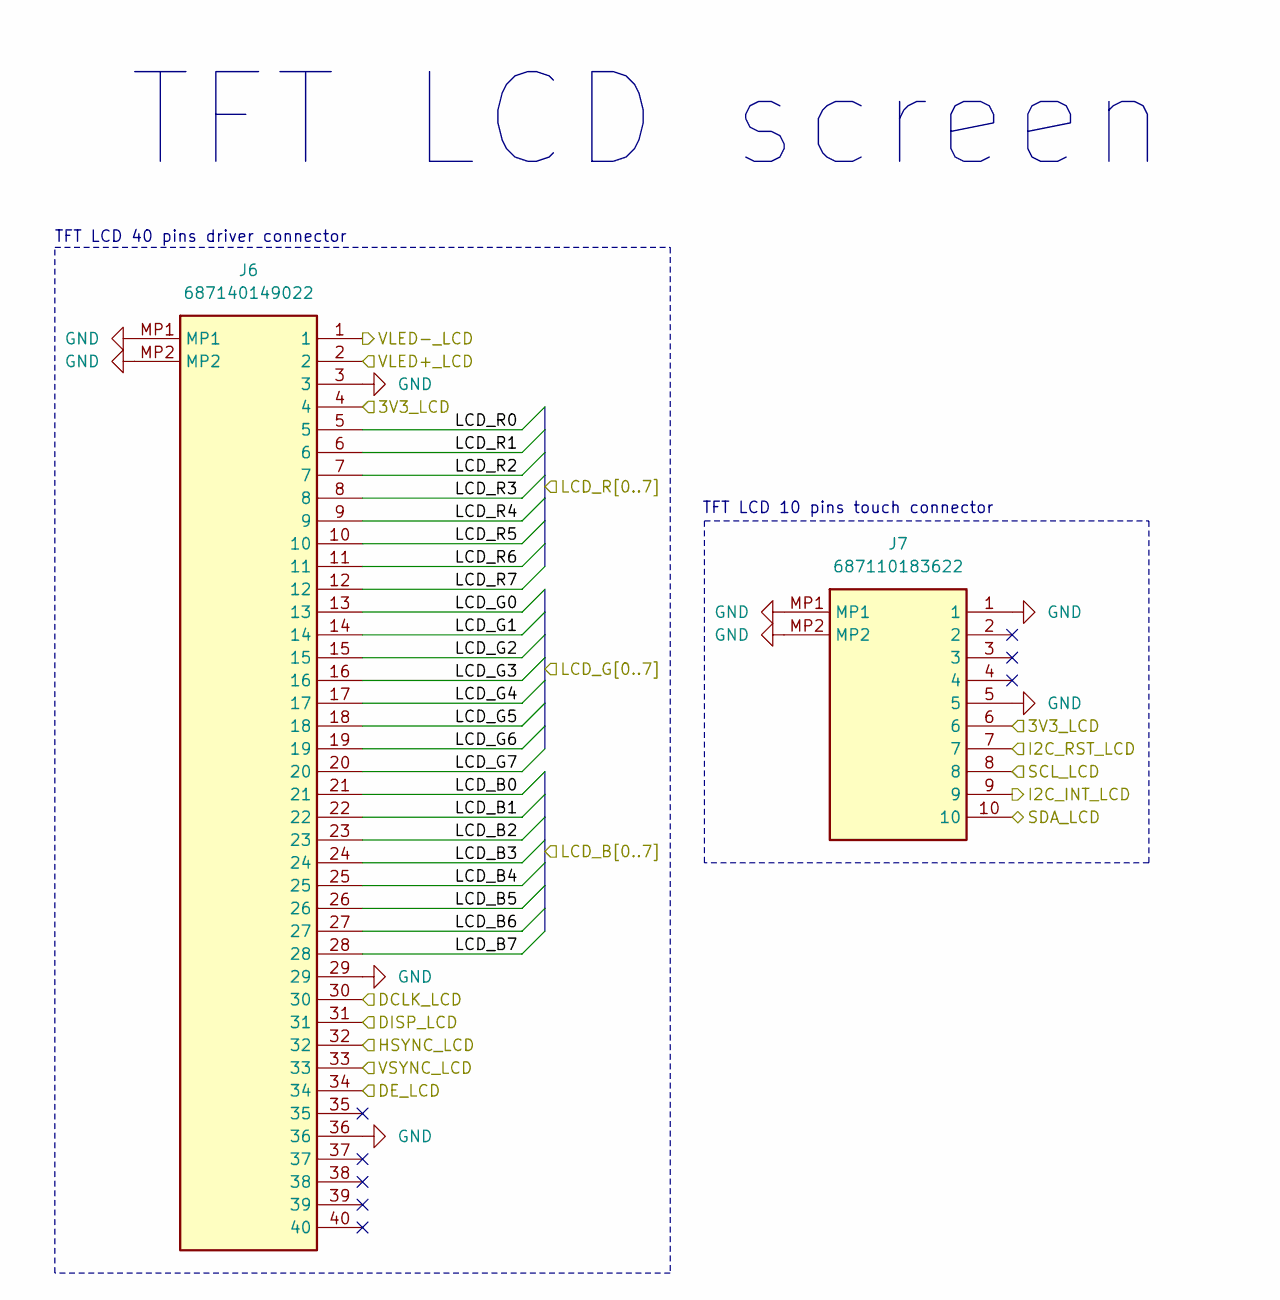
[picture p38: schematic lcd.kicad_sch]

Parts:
J6: 687140149022; Mouser Part Number 710-687140149022
J7: 687110183622; Mouser Part Number 710-687110183622

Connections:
+3V3_CONT: J6.4, J7.6; also elsewhere on the board
/lcd/DCLK_LCD: J6.30; also elsewhere on the board
/lcd/DE_LCD: J6.34; also elsewhere on the board
/lcd/DISP_LCD: J6.31; also elsewhere on the board
/lcd/HSYNC_LCD: J6.32; also elsewhere on the board
/lcd/I2C_INT_LCD: J7.9; also elsewhere on the board
/lcd/I2C_RST_LCD: J7.7; also elsewhere on the board
/lcd/LCD_B0: J6.21; also elsewhere on the board
/lcd/LCD_B1: J6.22; also elsewhere on the board
/lcd/LCD_B2: J6.23; also elsewhere on the board
/lcd/LCD_B3: J6.24; also elsewhere on the board
/lcd/LCD_B4: J6.25; also elsewhere on the board
/lcd/LCD_B5: J6.26; also elsewhere on the board
/lcd/LCD_B6: J6.27; also elsewhere on the board
/lcd/LCD_B7: J6.28; also elsewhere on the board
/lcd/LCD_G0: J6.13; also elsewhere on the board
/lcd/LCD_G1: J6.14; also elsewhere on the board
/lcd/LCD_G2: J6.15; also elsewhere on the board
/lcd/LCD_G3: J6.16; also elsewhere on the board
/lcd/LCD_G4: J6.17; also elsewhere on the board
/lcd/LCD_G5: J6.18; also elsewhere on the board
/lcd/LCD_G6: J6.19; also elsewhere on the board
/lcd/LCD_G7: J6.20; also elsewhere on the board
/lcd/LCD_R0: J6.5; also elsewhere on the board
/lcd/LCD_R1: J6.6; also elsewhere on the board
/lcd/LCD_R2: J6.7; also elsewhere on the board
/lcd/LCD_R3: J6.8; also elsewhere on the board
/lcd/LCD_R4: J6.9; also elsewhere on the board
/lcd/LCD_R5: J6.10; also elsewhere on the board
/lcd/LCD_R6: J6.11; also elsewhere on the board
/lcd/LCD_R7: J6.12; also elsewhere on the board
/lcd/SCL_LCD: J7.8; also elsewhere on the board
/lcd/SDA_LCD: J7.10; also elsewhere on the board
/lcd/VLED+_LCD: J6.2; also elsewhere on the board
/lcd/VLED-_LCD: J6.1; also elsewhere on the board
/lcd/VSYNC_LCD: J6.33; also elsewhere on the board
GND: J6.3, J6.29, J6.36, J6.MP1, J6.MP2, J7.1, J7.5, J7.MP1, J7.MP2; also elsewhere on the board

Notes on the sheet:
TFT LCD 40 pins driver connector
TFT LCD 10 pins touch connector
TFT LCD screen

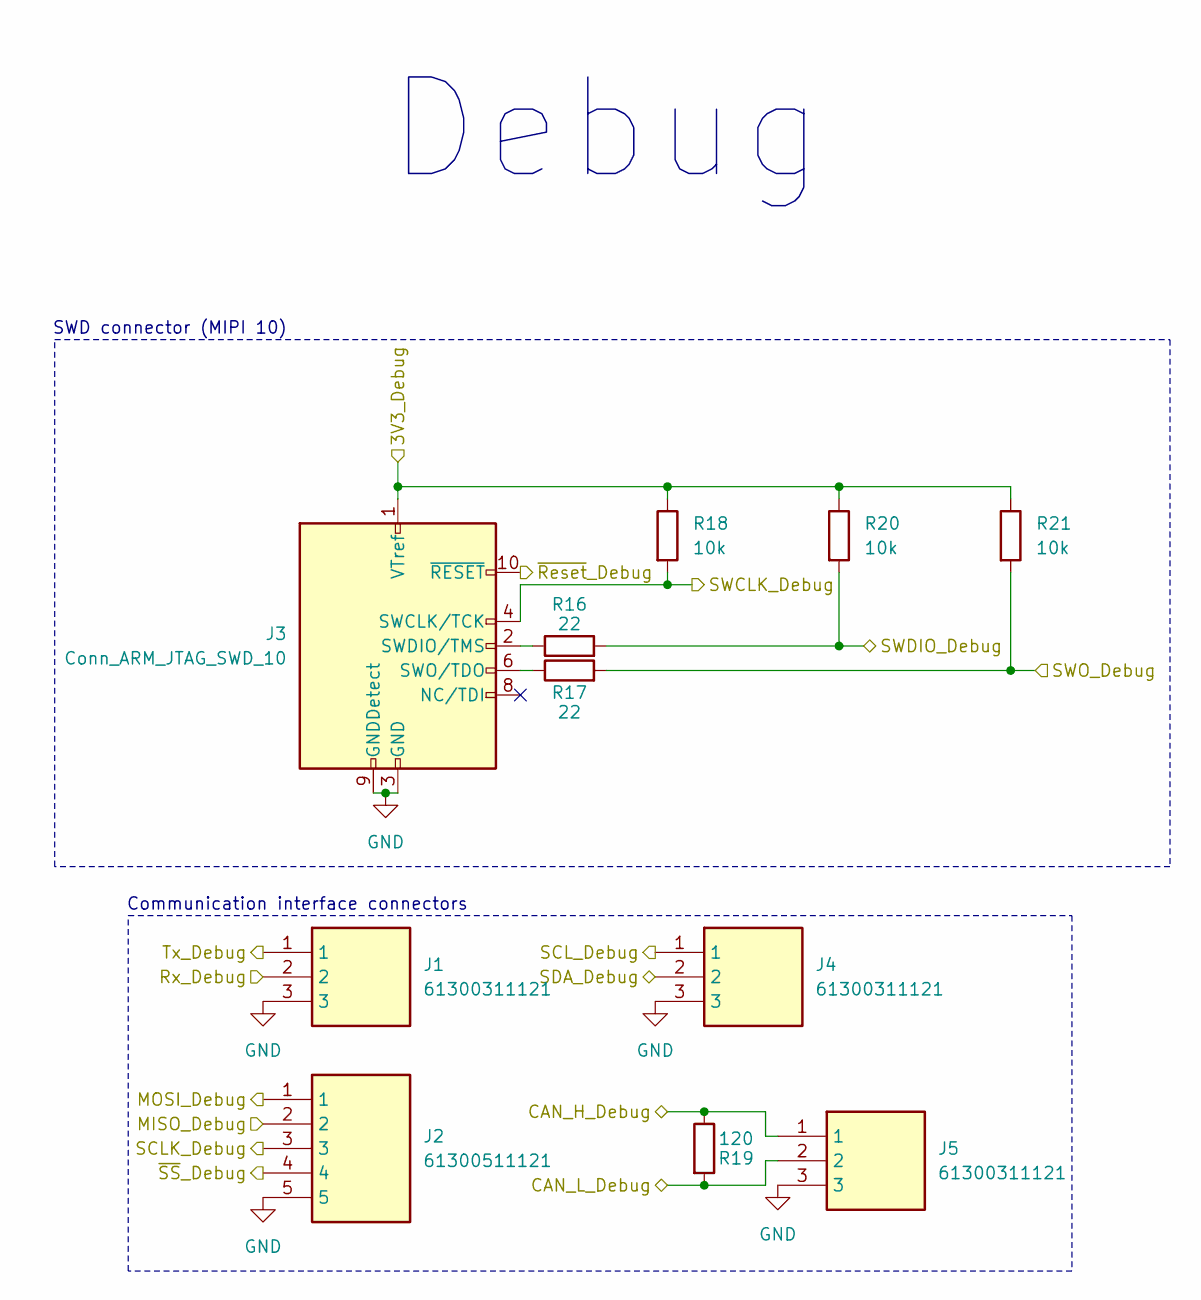
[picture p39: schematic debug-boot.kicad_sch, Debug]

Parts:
J1, J4, J5: 61300311121; HDRV3W64P0X254_1X3_762X254X869P; Mouser Part Number 710-61300311121
J2: 61300511121; HDRV5W64P0X254_1X5_1270X254X854P; Mouser Part Number 710-61300511121
J3: Conn_ARM_JTAG_SWD_10; FTSH10501LDVK; Manufacturer_Part_Number FTSH-105-01-L-DV-K
R16, R17: 22; R_0603_1608Metric_Pad0.98x0.95mm_HandSolder; Manufacturer_Part_Number 560112116043
R18, R20, R21: 10k; R_0603_1608Metric_Pad0.98x0.95mm_HandSolder; Manufacturer_Part_Number 560112116005
R19: 120; R_0603_1608Metric_Pad0.98x0.95mm_HandSolder; Manufacturer_Part_Number 560112116092

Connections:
+3V3_CONT: J3.1 (VTref), R18.1, R20.1, R21.1; also elsewhere on the board
/debug-boot/CAN_H_Debug: J5.1, R19.1; also elsewhere on the board
/debug-boot/CAN_L_Debug: J5.2, R19.2; also elsewhere on the board
/debug-boot/MISO_Debug: J2.2; also elsewhere on the board
/debug-boot/MOSI_Debug: J2.1; also elsewhere on the board
/debug-boot/Rx_Debug: J1.2; also elsewhere on the board
/debug-boot/SCLK_Debug: J2.3; also elsewhere on the board
/debug-boot/SCL_Debug: J4.1; also elsewhere on the board
/debug-boot/SDA_Debug: J4.2; also elsewhere on the board
/debug-boot/SWCLK_Debug: J3.4 (SWCLK/TCK), R18.2; also elsewhere on the board
/debug-boot/SWDIO_Debug: R16.2, R20.2; also elsewhere on the board
/debug-boot/SWO_Debug: R17.2, R21.2; also elsewhere on the board
/debug-boot/Tx_Debug: J1.1; also elsewhere on the board
/debug-boot/~Reset_Debug: J3.10 (~RESET); also elsewhere on the board
/debug-boot/~SS_Debug: J2.4; also elsewhere on the board
GND: J1.3, J2.5, J3.3 (GND), J3.5 (GND), J3.9 (GNDDetect), J4.3, J5.3; also elsewhere on the board
unnamed: J3.2 (SWDIO/TMS), R16.1
unnamed: J3.6 (SWO/TDO), R17.1

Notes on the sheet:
Debug
SWD connector (MIPI 10)
Communication interface connectors

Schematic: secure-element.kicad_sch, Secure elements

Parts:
C74: 10u; C_0603_1608Metric_Pad1.08x0.95mm_HandSolder; Manufacturer_Part_Number GRM188Z71A106KA73D
C75: 100n; C_0603_1608Metric_Pad1.08x0.95mm_HandSolder; Manufacturer_Part_Number 885012206020
IC7: STSAFA110S8OCD03; SOIC127P600X175-8N; Mouser Part Number 511-STSAFA110S8OCD03

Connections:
+3V3_CONT: C74.1, C75.1, IC7.2 (VCC); also elsewhere on the board
/lcd/SCL_LCD: IC7.7 (SCL); also elsewhere on the board
/lcd/SDA_LCD: IC7.5 (SDA); also elsewhere on the board
/mcu/~RESET_STSAFE_MCU: IC7.1 (~RESET); also elsewhere on the board
GND: C74.2, C75.2, IC7.4 (GND); also elsewhere on the board

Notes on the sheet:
STSAFE-A110
Secure element (STSAFE)

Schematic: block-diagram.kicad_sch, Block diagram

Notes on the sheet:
JLCPCB stackup
L1 and L4 have a direct return paths through solid ground plane on L2 and L3. But Pwr on L1 is perhaps an issue in terms of EMC ?
7628 FR DK = 4.4 So 0.3mm trace width => 54.9 ohms For USB differentials pairs, 0.3mm trace width and 0.3mm spacing => 96.4 ohms (90 ohms +/- 10% for USB) Calculation according PCB way impedance calculator : (https://www.pcbway.com/pcb_prototype/impedance_calculator.html)
PCB build up

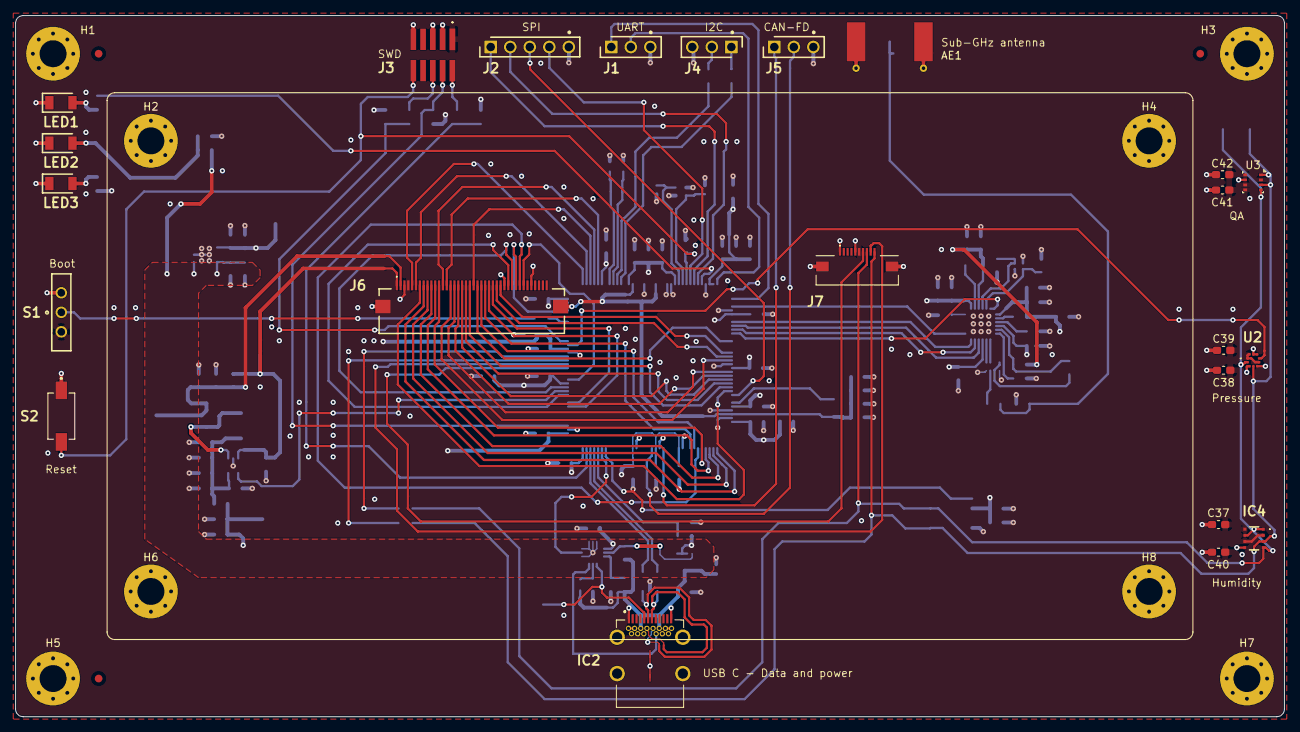
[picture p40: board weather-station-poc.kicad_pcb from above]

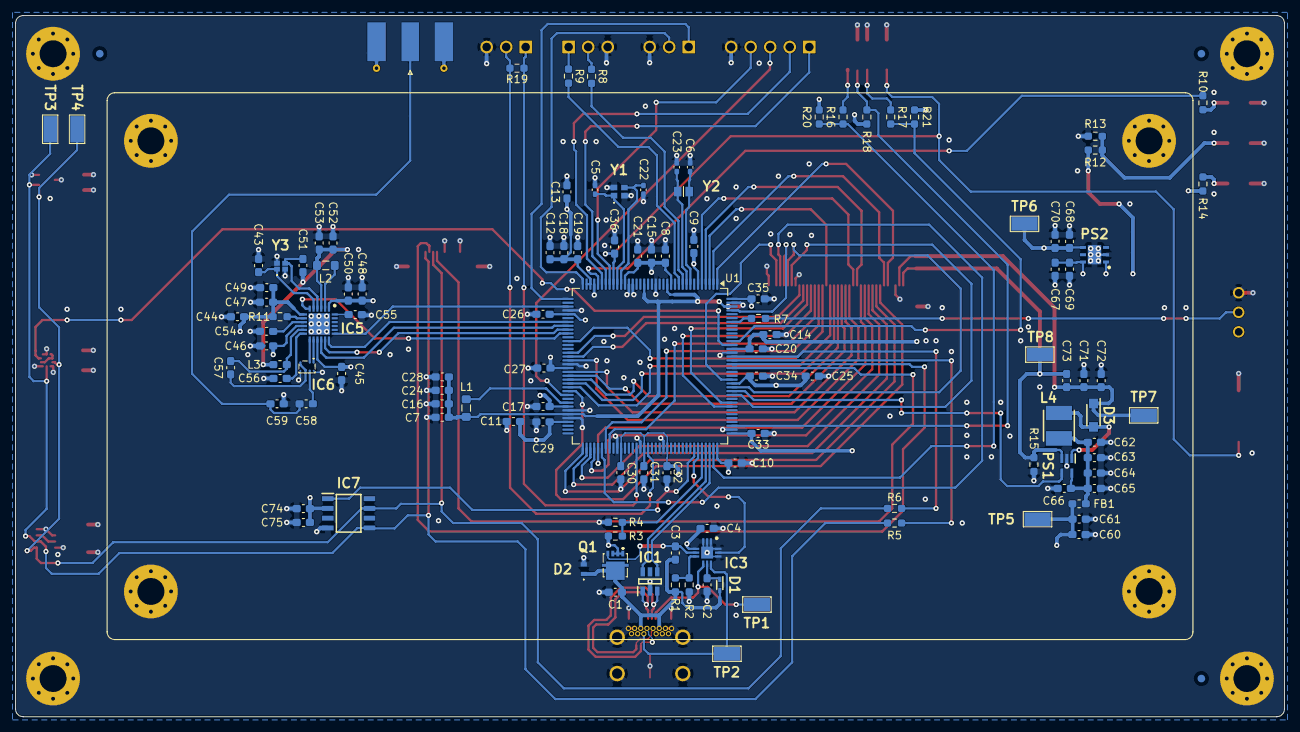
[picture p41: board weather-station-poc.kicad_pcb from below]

Board: 4 copper layers, 165.0 x 91.2 mm, 155 parts (122 on the bottom side), 106 nets.

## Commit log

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2025-11-01 Choose the right STM32 for the project Closes #3
    [weather-station-poc.kicad_sch]
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2025-11-30 Use local labels for RGB bus in folio and add title for all folio
    [Ethernet.kicad_sch, debug_boot.kicad_sch, lcd.kicad_sch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]
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2025-12-01 Add external Ethernet PHY in SPI (limited to 10 Mbits/s)
    [Ethernet.kicad_sch]
2025-12-01 Add LCD signals to MCU and LCD folios
    [mcu.kicad_sch, weather-station-poc.kicad_sch]
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2025-12-06 Add crystal oscillator and button for reset
    [debug_boot.kicad_sch, mcu.kicad_sch]
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2025-12-07 Fix some ERC errors
    [Ethernet.kicad_sch, lcd.kicad_sch, mcu.kicad_sch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]
2025-12-07 Fix warnings for footprint
    [Ethernet.kicad_sch, lcd.kicad_sch, mcu.kicad_sch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]
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2025-12-07 Modify symbols of LDO and S2LP
    Symbols for LDO and S2LP are inconsistent, because LDO VOUT pin was not in POWER OUTPUT type and S2LP wait for POWER INPUT on VDDS ... Moreover, decoupling capacitors on S2LP was a hell, because ERC 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
    [power.kicad_sch, radio.kicad_sch]
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2025-12-07 Add status LED for MCU and power supplies
    [mcu.kicad_sch, power.kicad_sch]
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2025-12-12 Finish ethernet schematic and add second LDO for wake/sleep of ETH
    [Ethernet.kicad_sch, power.kicad_sch, weather-station-poc.kicad_sch]
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2025-12-14 Reorganise synoptic schematic for better reading Closes #26
    [Ethernet.kicad_sch, SecureElement.kicad_sch, lcd.kicad_sch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]
2025-12-16 Fix errors in synoptic and hierarchic pins
    [debug_boot.kicad_sch, mcu.kicad_sch, power.kicad_sch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]
2025-12-16 Fix error on SS SPI pin direction for debug
    [weather-station-poc.kicad_sch]
2025-12-16 Add decoupling capacitors for USB C power sink
    [usb-c.kicad_sch]
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2025-12-21 Fix some little warnings and refomat schematics files
    [Ethernet.kicad_sch, SecureElement.kicad_sch, debug_boot.kicad_sch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]
2025-12-21 Replace sub d 9 connectors by pin headers for CAN
    Sub D 9 pts connectors are imposant on PCB
    [debug_boot.kicad_sch]
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2025-12-21 Remove Ethernet part, critical error, LAN8651 is 10BASE-T1S !
    10BASE-T1S is not suitable with RJ45 connector and not connectable to computer
    [mcu.kicad_sch, power.kicad_sch, weather-station-poc.kicad_sch]
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2025-12-23 Setup crystal oscillators for MCU and S2LP
    [mcu.kicad_sch, radio.kicad_sch]
2025-12-23 Add switch reference form WE for boot selection mode
    [mcu.kicad_sch]
2025-12-23 Add a button reference for reset MCU
    [mcu.kicad_sch]
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2025-12-26 Replace coma by semicolon in BOM for Excel
    [weather-station-poc.csv]
2025-12-26 Add footprints for inductors, missing one for L6
    [mcu.kicad_sch, radio.kicad_sch]
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2025-12-26 Add a new reference for L6 inductor on boost converter
    [power.kicad_sch, weather-station-poc.kicad_pcb]
2025-12-26 Update PCB layout and remove unused PDF
    Deleted the unused DS_RVT50HQTFWCA0_Rev.1.0 (1).pdf from docs. Updated weather-station-poc.kicad_pcb with significant component repositioning, including capacitors, resistors, ICs, LEDs, connectors, 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
    [weather-station-poc.kicad_pcb]
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2026-01-02 LCD 10 pins connector is top and not bottom face, replace connector part
    [lcd.kicad_sch, weather-station-poc.kicad_pcb]
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2026-01-04 Add ferrite bead part number in power schematic
    [power.kicad_sch, weather-station-poc.kicad_pcb]
2026-01-04 Add 3D models to some components and move JTAG connector
    [weather-station-poc.kicad_pcb]
2026-01-11 Remove L5 inductos on radio oscillator
    [power.kicad_sch, radio.kicad_sch, weather-station-poc.kicad_pcb]
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2026-01-12 Place 4 others hole on the border of the PCB, TODO: place its correctly
    [weather-station-poc.kicad_pcb]
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2026-01-17 Place all components on the PCB correctly
    [SecureElement.kicad_sch, debug_boot.kicad_sch, lcd.kicad_sch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]
2026-01-18 Align all components on PCB to have a good design
    [weather-station-poc.kicad_pcb]
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2026-01-20 Use default stack up from PCB Way and enable controled impedance option
    [weather-station-poc.kicad_pcb]
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2026-01-21 Bad placement of serigraphy on bottom for some components
    [weather-station-poc.kicad_pcb]
2026-01-25 Place J6 and J7 FFC connector to take in account spacer height
    [weather-station-poc.kicad_pcb]
2026-02-01 Modify USB data signals name to trace diff pairs
    [mcu.kicad_sch, usb-c.kicad_sch, weather-station-poc.kicad_pcb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]
2026-02-01 Add mounting holes with pads in schematic and place it into pcb
    [weather-station-poc.kicad_pcb, weather-station-poc.kicad_sch]
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2026-02-19 Use SMA coaxial connector for antenna, PCB antenna later
    [radio.kicad_sch, weather-station-poc.kicad_pcb]
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2026-02-23 Place all vias for GND and add fiducials on top and bottom
    [weather-station-poc.kicad_pcb, weather-station-poc.kicad_sch]
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2026-03-28 Add 3V3 copper pour on L1 and connect to nets
    [usb-c.kicad_sch, weather-station-poc.kicad_pcb]
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2026-03-29 End of routing and DRC rules check fix
    [weather-station-poc.kicad_pcb]
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2026-03-29 Use green PCB instead of black, as the proto probably would not work
    [weather-station-poc.kicad_pcb]
2026-03-30 Add serigraphy to identify GND on HE14 pins headers
    [weather-station-poc.kicad_pcb]
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2026-04-03 Add tests points with 5015 footprint for practicity
    [SecureElement.kicad_sch, debug_boot.kicad_sch, lcd.kicad_sch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]
2026-04-03 Do no mount antenna coaxial antenna, to be soldered after by hand
    [radio.kicad_sch, weather-station-poc.kicad_pcb]
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2026-04-06 Add pull ups resistors for I2C bus and reformat some schematic files
    [debug_boot.kicad_sch, mcu.kicad_sch, power.kicad_sch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]
2026-04-07 Add transfer vias for L1 to L4 transition
    [weather-station-poc.kicad_pcb]
2026-04-10 Complete all references for components
    Modifgy Y1 and Y2 capacitors footprint from 0603 to 0402
    Modify footprint of SWD connector
    [SecureElement.kicad_sch, debug_boot.kicad_sch, mcu.kicad_sch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]
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2026-04-14 Use JLCPCB standard stackup and so modify trace width for 50 ohm and 90 ohm diff
    [weather-station-poc.kicad_pcb]
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2026-04-19 Create BOM in JLCPCB format and create CPL file
    [weather-station-poc-jlcpcb.xlsx, weather-station-poc.csv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]
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2026-05-01 Set I2C address for BMP sensors and document address
    [block-diagram.kicad_sch, mcu.kicad_sch, sensors.kicad_sch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]
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2026-07-19 Fiw warnings concerning multiple name for the same label
    [mcu.kicad_sch, power.kicad_sch, radio.kicad_sch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]
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2026-07-19 Move SWD debug connector from debug sheet to MCU sheet
    [debug-boot.kicad_sch, lcd.kicad_sch, mcu.kicad_sch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]
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2026-08-11 Add RVT50HQTFWCA0 documentation link into a connector properpty
    [lcd.kicad_sch]
2026-08-14 Add a step down regulator to convert 5V to 3.3V
    [power.kicad_sch]
2026-08-14 Reset components indexing
    [debug.kicad_sch, lcd.kicad_sch, mcu.kicad_sch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]
2026-08-14 No rules must be ignored during PCB design, so move ignored rules to warned rules
    [weather-station-poc.kicad_pcb]
2026-08-14 Set trace width and spacing for diff pairs from 0.3mm to 0.35mm for more precision on characteristic impedance
    [block-diagram.kicad_sch]
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2026-08-21 Fix some GND shielding leaks
    [weather-station-poc.kicad_pcb]
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2026-08-28 Create an output folder to store position file and bom
    [weather-station-poc-jlcpcb.xlsx, weather-station-poc.csv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]
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2026-09-27 Add missing 3D models
    [weather-station-poc.kicad_pcb]
2026-10-11 End of trace routing
    Missing power plane on layer 2
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
